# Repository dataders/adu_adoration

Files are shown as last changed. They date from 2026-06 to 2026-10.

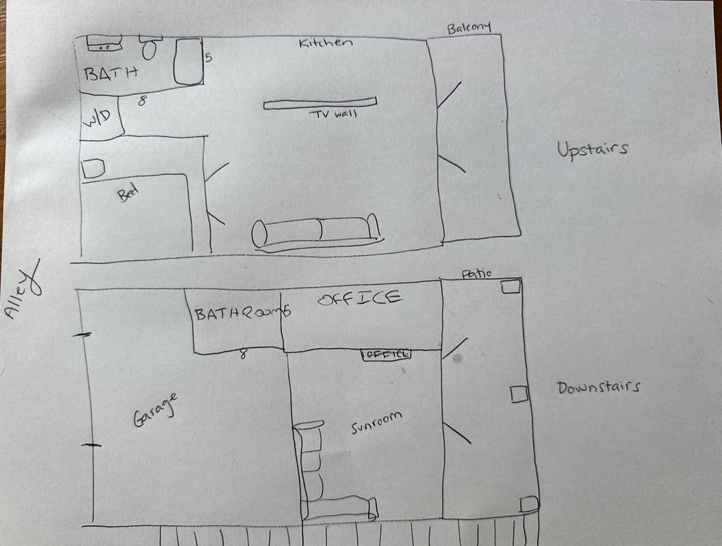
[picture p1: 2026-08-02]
images/12-handdrawn-two-level-design-basis.jpg

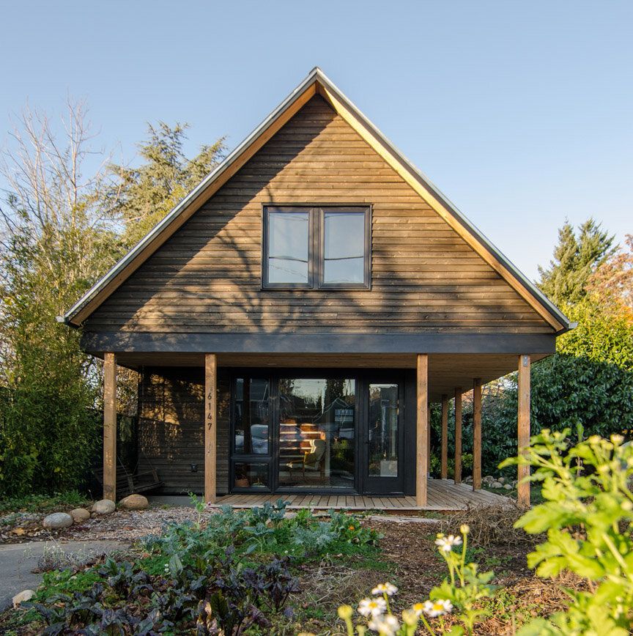
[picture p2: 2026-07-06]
inspiration/pin-407012885098092626-polyphon-architecture-design-llc-a-portland-oreg.jpg

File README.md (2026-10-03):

# ADU planning — 112 W 29th St, Richmond, Virginia

Design studies, source records, generated plans, and coordinated 3D artifacts for a
proposed detached accessory dwelling unit (ADU) at **112 W 29th St** (PID 43615 / PIN
S0001130005), Richmond, VA 23225.

## Project status

**Option F revision 2 is the current schematic owner study.** It is a 20 × 24 ft, two-story detached
building with a full-depth garage/shop and owner office below, an approximately 480 sf
one-bedroom apartment above, a south exterior stair, and stacked east patios. The working ridge datum is 19 ft 10 in; official height measurement and applicable zoning limits remain unverified.

Start with these files:

1. [Construction and engineering basis](output/pdf/adu-option-f-construction-engineering-basis.pdf)
   — schematic owner-coordination set, regenerated from the revision 2 geometry.
2. [Option F floor plans](apartment/option-f-recommended-development.svg) — current room,
   opening, stair, landing, and patio layout.
3. [Option F site plan](plan/site-plan-option-f-architect.pdf) — current placement,
   setbacks, access, and replacement-shed response.
4. [Interactive site model](model/site-model-3d.html#yard) — browser-based whole-site
   model with furnished floor cutaways and roof controls; serve over local HTTP as below.
5. [Coordination manifest](option-f-artifact-manifest.json) — machine-readable authority,
   version, invariants, and current-versus-historical artifact boundary.

Option E is the owner-sketch baseline. Options A–E and their model artifacts remain useful
design history, but they do not override Option F. Current model renderings use the same exported scene as the browser viewer. Earlier AI images are mood references only and do not govern geometry.

The earlier balcony-entry study in `plan/floor-plans-balcony-scheme.{svg,png}` and
`renderings/massing-3d-interactive.html` is retained as historical reference only. It does
not override the current Option F authority.

> This repository contains schematic design work, not sealed permit or construction
> documents. Survey, zoning determinations, code analysis, structural engineering, energy
> compliance, utility verification, and trade design still require qualified professionals.

## Working design basis

| Item | Current basis |
|---|---|
| Lot | 45 × 148 ft; approximately 6,660 sf; R-5 |
| Existing house | 1,303 sf; one story; built 1931 |
| Orientation | Alley west/rear; W 29th St east/front |
| ADU envelope | 24 ft east–west × 20 ft north–south; 480 sf gross per level |
| ADU vertical datums | Upper subfloor 9.25 ft; eave 16 ft; ridge 19.833 ft |
| ADU site position | 5 ft from alley/rear line and 5 ft from north line |
| Exterior access | 14 risers / 13 treads; connected south landing and 4-ft east patios |
| Replacement shed | 18 × 6 ft maximum envelope; 108 sf; 5 ft clear south of ADU access |
| Field measurement | 25 ft front setback confirmed 2026-06-28 |

Revision 2 retains a 23-ft-clear garage/shop bay and approximately 70-sq-ft northeast garden office. The lower hall is 39 inches clear. A northwest powder room stacks below the upper bath; upstairs laundry opens directly to common space. An L-shaped kitchen with peninsula replaces the island, and the TV moves to the bedroom partition. Schematic furniture clearances are 53.6 inches west of the peninsula, 38.4 inches from sofa to slider route, and 39.6 inches from dining chairs to counter. These are drawing checks, not code-compliance findings.

A separate [garden-room alternative](apartment/option-f-alternative-garden.svg) trades parking depth (18 ft clear) for approximately 121 sq ft of connected garden space. It is exploratory and does not override the current CAD or model.

[`model/option_f_geometry.py`](model/option_f_geometry.py) is the canonical geometry source. Generated drawings, CAD, browser mesh, and renderings must agree with it; stale generated artifacts do not override source intent. Finished headroom, wall/floor/roof assemblies, and appliance operation remain design holds.

The existing field-measured 12 × 18 ft shed is designated for removal. The assessor record
instead describes a 360 sf detached garage; reconcile that discrepancy during survey and
permitting.

## Quick start

Requires [uv](https://docs.astral.sh/uv/) and Python 3.11 or newer.

```sh
uv sync --group dev --group architecture
./bin/check
```

`./bin/check` runs Ruff lint and format checks, ty type checking, then the architecture
artifact suite. The architecture checks audit the Option F DXF and access geometry, compare
the coordination and model manifests, load the STEP solids with OpenCascade, verify actual door apertures and furniture clearances, compare the viewer against the canonical scene, validate render provenance hashes, inspect the GLB container, and parse committed PDF/PNG outputs. The model manifest counts physical solids separately from the ten nonphysical room zones. CI also runs the official Khronos glTF
Validator and requires zero errors and warnings.

Install optional commit hooks with:

```sh
uv run --group dev pre-commit install
```

## Regenerating artifacts

Run generators from the repository root. Commit source and regenerated artifacts together,
then run `./bin/check`.

```sh
# Floor-plan studies (SVG and PNG)
uv run python apartment/generate_floorplans.py

# Current Option F site plan (DXF and PDF)
uv run python plan/generate_site_plan.py --option F

# Current Option F building model (STEP, BREP, GLB, OBJ, manifest)
uv run --group architecture python model/generate_option_f_model.py

# Whole-site viewer and OBJ
uv run python model/generate_3d_model.py

# Schematic drawing set PDF
uv run python plan/generate_construction_basis_set.py

# Model-derived exterior and furnished cutaway images (Blender executable required)
blender --background --python model/render_model.py -- --views yard alley upper lower

# Preview static website and viewer (ES modules require HTTP, not file://)
uv run --no-project python -m http.server 8000
```

Open [the local website](http://localhost:8000/) or [the full-screen model](http://localhost:8000/model/site-model-3d.html#yard). Three.js 0.186.1 is vendored locally. Render provenance is recorded in [`renderings/model-render-manifest.json`](renderings/model-render-manifest.json), including hashes of the source scene, renderer, and each image.

Some historical Option E exports require FreeCAD or Sweet Home 3D. See
[model/README.md](model/README.md) before changing them.

## Repository map

| Path | Purpose |
|---|---|
| [`apartment/`](apartment/) | Historical studies A–E, revision 2 floor sheets, garden alternative, and generator |
| [`plan/`](plan/) | Current Option F and historical Option E site plans plus plan-set generator |
| [`model/`](model/) | Option F geometry contract, generators, CAD/mesh exports, whole-site viewer, and historical Option E models |
| [`output/pdf/`](output/pdf/) | Current combined concept and construction/engineering basis sets |
| [`renderings/`](renderings/) | Model-derived revision 2 images and archived AI mood references |
| [`images/`](images/) | Measured sketches, site photos, assessor sketch, and satellite references |
| [`documents/`](documents/) | Source property and owner PDFs |
| [`inspiration/`](inspiration/) | Curated and Pinterest-synced style references |
| [`sync/`](sync/) | Pull-only public Pinterest RSS sync |
| [`scripts/`](scripts/) | Repository validation implementation |
| [`bin/`](bin/) | Stable developer entry points |
| [`index.html`](index.html) | Static public project brief |
| [`requirements.html`](requirements.html) | Static high-level requirements brief |

Folder-specific documentation:

- [Floor-plan decisions and constraints](apartment/README.md)
- [3D formats and historical model boundary](model/README.md)
- [Source documents](documents/README.md)
- [Reference imagery](images/README.md)
- [Inspiration library](inspiration/README.md)
- [Pinterest sync](sync/README.md)
- [Agent/developer workflow](CLAUDE.md)

## Pinterest inspiration sync

The sync mirrors new images from a public Pinterest board into `inspiration/` through the
board RSS feed. It uses no login or API token and never pushes or deletes pins.

```sh
uv run --no-project python sync/pinterest_pull.py --dry-run
uv run --no-project python sync/pinterest_pull.py
```

See [sync/README.md](sync/README.md) for board setup and limitations.

## Open coordination items

- Confirm the working 5-ft north setback, roof projections, openings, and fire-separation
  strategy with Richmond zoning/building review.
- Reconcile field-measured shed dimensions with the assessor record.
- Verify survey, soil, grading, drainage, and utility locations.
- Resolve final roof/floor section, stair and guard details, structure, MEP, egress, and
  conditioned-area treatment with the design team.

## Research sources

Property data came from the saved [actDataScout report](documents/richmond-datascout-report-S0001130005.pdf)
and assessor sketch. Field sketches and measurements are in `documents/` and `images/`.

Zoning research was last checked August 12, 2026. The September design revision does not refresh legal or code findings. Earlier research used these City and Municode sources:

- [City of Richmond ADU guidance](https://www.rva.gov/planning-development-review/accessory-dwelling-units)
- [Richmond zoning ordinance, Chapter 30](https://library.municode.com/va/richmond/codes/code_of_ordinances)
- [R-5 district provisions](https://library.municode.com/va/richmond/codes/code_of_ordinances?nodeId=CH30ZO_ARTIVDIRE_DIV6SIMIREDI)
- [Accessory-building provisions](https://library.municode.com/va/richmond/codes/code_of_ordinances?nodeId=CH30ZO_ARTVISURE_DIV9ACBU)
- [Richmond Code Refresh](https://www.rva.gov/planning-development-review/code-refresh)

Relevant research notes cite §§30-410.4–.7, 30-620.1, 30-680.1, and 30-680.4. Recheck
current law and obtain written determinations before relying on those notes.

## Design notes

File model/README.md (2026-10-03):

# Option F revision 2 — shared 3D geometry

Current schematic owner study for a 24 × 20 ft ADU, with a garage and garden office below a 480-sq-ft gross apartment. Geometry is defined in [`option_f_geometry.py`](option_f_geometry.py). Site placement and existing buildings are working assumptions, not a surveyed or approved model.

## View the project

The viewer uses ES modules and must be served over HTTP. From repository root:

```sh
uv run --no-project python -m http.server 8000
```

Open [the project](http://localhost:8000/) or [the model](http://localhost:8000/model/site-model-3d.html#yard). Directly opening the HTML as `file://` is unsupported. Three.js 0.186.1 and its controls are vendored under `vendor/`; the viewer needs no CDN. The five view links are `#yard`, `#alley`, `#level1`, `#level2`, and `#site`. Drag to orbit, scroll/pinch to zoom, toggle the roof or furniture, and use furnished cutaways to inspect circulation. A static-image fallback is shown when WebGL cannot initialize.

## Current files and authority

- **`option_f_geometry.py`** — canonical feet/Z-up dimensions, openings, partitions, rooms, furniture, and checked circulation widths. Southwest building corner is origin; X east, Y north, Z up.
- **`generate_option_f_model.py`** — generates physical model components, cuts real wall apertures, and exports exact meshes plus neutral CAD.
- **`adu-option-f-scene.json`** — shared exact mesh data and semantic parts. Ten room zones are nonphysical metadata and are excluded from CAD/GLB/OBJ physical-solid counts.
- **`adu-option-f.step`**, **`.brep`** — physical schematic solids, in millimetres/Z-up. The manifest reports source geometry in feet.
- **`adu-option-f.obj`** — building mesh in feet/Z-up. **`adu-option-f.glb`** uses metres/Y-up.
- **`adu-option-f-manifest.json`** — version, physical-solid count, all semantic parts, datums, bounds, and circulation widths.
- **`site-model-3d.html`** — generated viewer with the exact canonical scene embedded. **`viewer-template.html`**, **`viewer.js`**, and **`viewer.css`** own its interface.
- **`site-model.obj`** — canonical building translated into site coordinates plus approximate context, in feet/Z-up. Pair with [`../plan/site-plan-option-f.dxf`](../plan/site-plan-option-f.dxf). `site-model.mtl` is retained from the earlier export and does not define current geometry.
- **`render_model.py`** — Blender renderer for model-derived exterior and furnished cutaway images; adds materials, lighting, ground, and sparse landscape context rather than inventing building geometry.

Regenerate in dependency order:

```sh
uv run --group architecture python model/generate_option_f_model.py
uv run python model/generate_3d_model.py
blender --background --python model/render_model.py -- --views yard alley upper lower
./bin/check
```

The four images are `renderings/option-f-yard-model.png`, `option-f-alley-model.png`, `option-f-upper-cutaway.png`, and `option-f-lower-cutaway.png`. `renderings/model-render-manifest.json` records source scene, image, and renderer SHA-256 hashes. Run all four views after geometry changes. Earlier AI images remain historical mood references.

## Revision 2 decisions

The 39-inch-clear downstairs hall connects the powder room and approximately 70-sq-ft garden office while retaining 23 ft of parking depth. Upstairs has an L-shaped kitchen and peninsula, common-space laundry access, and a TV on the bedroom partition. A separate approximately 121-sq-ft garden-room study shortens parking depth to 18 ft; it is not represented in the selected model.

Vertical datums remain +9.25 ft upper subfloor, +16 ft eave, and +19.833333 ft ridge. The exterior stair has fourteen risers from the +0.5 ft ground landing to the upper floor. The roof assembly allowance is provisional; finish headroom and actual assemblies require professional design. Four-foot exterior patios are principally circulation, and guard details and usable clear widths remain unresolved.

### Historical Option E FreeCAD model

Files below are retained only to document the previous Option E study. They are
not current geometry and must not be used to override Option F plans or models.

- **`adu-option-e.FCStd`** — editable two-level Option E model. Organized into
  Level 1, Level 2, exterior access, and roof groups, with named walls, room
  zones, openings, fixtures, cabinetry, patios, balcony, and 13-step exterior
  stair. Objects retain source/category/level metadata.
- **`adu-option-e.glb`** — compact, color-preserving glTF 2.0 binary for WebGL,
  `<model-viewer>`, Three.js, Blender, and other real-time viewers.
- **`adu-option-e.obj`** — generic triangulated Wavefront OBJ export.
- **`adu-option-e-arch.obj`** + **`adu-option-e-arch.mtl`** — FreeCAD BIM/Arch
  Wavefront export with named objects and color materials.
- **`adu-option-e-sweethome.obj`** + **`adu-option-e-sweethome.mtl`** — same
  Arch geometry transformed from millimetres/Z-up to centimetres/Y-up; preferred
  Sweet Home 3D import.
- **`adu-option-e-sweethome-simple.obj`** — single-mesh, no-material fallback
  for Sweet Home 3D installations where the multi-material loader stalls.
- **`adu-option-e.step`** — named, color-preserving STEP export for CAD tools.
- **`adu-option-e.brep`** — ASCII OpenCASCADE geometry for low-level textual
  inspection. Exact but noisy in Git diffs.
- **`adu-option-e-manifest.json`** — deterministic semantic summary of every
  object's name, category, level, color, bounds, area, volume, and topology;
  preferred human-readable Git diff.
- **`adu-option-e-level-1.png`**, **`adu-option-e-level-2.png`**, and
  **`adu-option-e-axon.png`** — checked FreeCAD views for quick review.
- **`generate_freecad_adu.py`** — deterministic native-FreeCAD generator using
  the dimensions in `apartment/generate_floorplans.py`.
- **`export_freecad_formats.py`** — regenerates all interchange and diff exports
  from the saved FCStd model.
- **`convert_arch_obj_to_glb.py`** — converts the color-material Arch OBJ from
  millimetres/Z-up to a web-oriented GLB in metres/Y-up.
- **`prepare_sweethome_obj.py`** — converts the Arch OBJ units and up-axis for
  an exact-scale Sweet Home 3D import.
- **`BuildSweetHomeProject.java`** — uses Sweet Home 3D's bundled model API to
  create separate, non-overlapping `adu-option-e-level-1.sh3d` and
  `adu-option-e-level-2.sh3d` editable floor plans. `adu-option-e-floorplans.sh3d`
  is retained as a clean Level 2 view. Each keeps the fallback OBJ as a hidden
  3D reference.
- **`export_colored_step_gui.py`** — FreeCAD GUI startup script that overwrites
  the headless STEP baseline with names and native AP214 presentation colors.
- **`apply_freecad_view.FCMacro`** — reapplies stored colors and the saved
  axonometric view after a headless regeneration.

FreeCAD 1.1.3 on macOS bundles Qt 6.8.3. Qt's ARM CPU probe fails inside the
Codex sandbox because that environment blocks `sysctlbyname`; run this command
outside the sandbox. FreeCAD's bundled Python plus explicit module path avoids
the macOS `freecadcmd` positional-script issue:

```sh
PYTHONPATH=/Applications/FreeCAD.app/Contents/Resources/lib \
  /Applications/FreeCAD.app/Contents/Resources/bin/python \
  model/generate_freecad_adu.py
```

Then open `adu-option-e.FCStd` in FreeCAD and run
`apply_freecad_view.FCMacro` from **Macro → Macros…**. FreeCAD stores geometry
in millimetres; source coordinates and plan metadata remain in feet.

Regenerate the headless interchange exports:

```sh
PYTHONPATH=/Applications/FreeCAD.app/Contents/Resources/lib \
  /Applications/FreeCAD.app/Contents/Resources/bin/python \
  model/export_freecad_formats.py

uv run --with trimesh --with numpy python3 \
  model/convert_arch_obj_to_glb.py

uv run --with trimesh --with numpy python3 model/prepare_sweethome_obj.py

/Applications/FreeCAD.app/Contents/Resources/bin/freecad \
  -u /tmp/adu-freecad-export-user.cfg \
  -s /tmp/adu-freecad-export-system.cfg \
  "$PWD/model/export_colored_step_gui.py"
```

This remains a design-development model, not construction documentation.
Architect must verify floor/roof section, structure, stair and guards, egress,
fire separation, plumbing, and zoning treatment.

## Heights used (estimates — field-verify)

| building | eave | ridge | notes |
|---|---|---|---|
| house | 10′ | 20′ | 1-story, gable ridge E–W, green siding |
| replacement shed | 7′ | 9.5′ | 18×6 low-profile massing, red slider on east gable end |
| ADU Option F | 16′ | 19′-10″ | +9′-3″ upper-subfloor basis; north eave and west rake flush pending zoning |

Footprints and setbacks follow the working site-plan basis (owner-measured front setback 25′, proposed ADU 5′ off alley / 5′ off north line), pending survey and zoning review.
Preliminary massing only — not for construction.

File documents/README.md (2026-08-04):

# Source documents

| File | What it is | Source |
|---|---|---|
| `richmond-datascout-report-S0001130005.pdf` | Full City of Richmond property report — lot dims, building sub-areas, photo, assessment, deed history | actDataScout, PIN `S0001130005` |
| `assessor-building-sketch-43615.pdf` | Assessor building footprint sketch with dimensions | actDataScout / PID 43615 |
| `site-plans-handdrawn-compressed.pdf` | Owner's hand-drawn site plans (3 pages, three scales) | Owner |

Notes:
- `site-plans-handdrawn-compressed.pdf` is downsampled from the original ~57 MB phone-photo PDF,
  which the owner retains outside the repository.
- actDataScout lookups: https://www.actdatascout.com/RealProperty/Virginia/Richmond

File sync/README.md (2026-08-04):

# Pinterest → `inspiration/` sync

One-way mirror of a **public** Pinterest board into this repo's
[`inspiration/`](../inspiration/) folder, using the board's RSS feed. No
Pinterest login, no API token, no signup.

## Quick start

```sh
# 1. Point it at your board (public boards only) — do this once:
echo 'https://www.pinterest.com/<user>/<board>/' > sync/board.txt

# 2. Preview what it would pull:
uv run --no-project python sync/pinterest_pull.py --dry-run

# 3. Actually pull new pins into inspiration/:
uv run --no-project python sync/pinterest_pull.py
```

You can also pass the URL directly instead of using `board.txt`:

```sh
uv run --no-project python sync/pinterest_pull.py https://www.pinterest.com/<user>/<board>/
```

Re-run it any time — it's idempotent. Already-downloaded pins are tracked in
[`manifest.json`](manifest.json), so a re-run only fetches **new** pins.

Synced pins land as `inspiration/pin-<id>-<slug>.jpg`. Your six hand-curated
`NN-*.jpg` references are never touched.

## What this does and doesn't do

| | |
|---|---|
| ✅ Pull new pins from a public board | Reads `<board-url>.rss` |
| ✅ Full-res images when available | Rewrites the CDN URL to `/originals/`, falls back to the RSS thumbnail |
| ✅ Idempotent re-runs | `manifest.json` records every pulled pin |
| ✅ Leaves your curated files alone | Only writes `pin-*.jpg` |
| ❌ **Push** repo images up to Pinterest | Needs the API v5 + OAuth token (see below) |
| ❌ **Delete-sync** | A pin removed on Pinterest is flagged (not deleted) locally |
| ❌ Private/secret boards | RSS is only exposed for public boards |

This is **pull-only** because that's the part that needs no credentials — which
is what you asked for. Creating or editing pins on Pinterest is impossible
without the authenticated API.

## Why not a Pinterest MCP?

There is no Pinterest connector in the Claude MCP directory (checked the
registry — it has monday.com, Miro, etc., but nothing Pinterest). So there's
nothing to "flip on"; a real integration has to talk to Pinterest's own API or,
as here, its RSS feed.

## Upgrading to full bidirectional (later, if you want it)

True two-way sync (pushing local images up as new pins) requires the
[Pinterest API v5](https://developers.pinterest.com/docs/api/v5/):

1. Create a Pinterest **business account** and a developer **app** at
   <https://developers.pinterest.com/>.
2. Request **trial access** (self-serve) — enough for a personal board.
3. Generate an **OAuth access token** with the `boards:read`, `pins:read`, and
   `pins:write` scopes.
4. Swap the RSS reader here for API calls:
   - Pull: `GET /v5/boards/{board_id}/pins` (full metadata + original images).
   - Push: `POST /v5/pins` with `media_source` of type `image_base64` to upload
     a local file as a new pin.

The `manifest.json` format here already tracks the pin↔file mapping you'd need
to avoid duplicate uploads, so it carries over.

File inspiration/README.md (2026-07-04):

# Inspiration

Reference photos of garage-ADUs / homes whose style we like, to steer the ADU design.

| File | Style notes |
|---|---|
| `01-gold-siding-black-windows-bay-tower.jpg` | Warm ochre lap siding, black windows, decorative shingled gable + 2-story angled bay/tower. Modern-traditional. |
| `02-modern-taupe-shed-roof-awning-windows.jpg` | Taupe lap siding, low **shed/skillion roof**, tilted awning-style windows, single garage bay, exterior side stair. Contemporary. |
| `03-craftsman-gray-red-trim-carriage-door.jpg` | Gray-green lap siding, white + **red window trim & red door**, wood **carriage garage door**, exposed rafters / knee braces, gable roof, lantern sconces. **Closest match to our 1931 Craftsman bungalow.** |
| `04-olive-carriage-door-balcony-cottage.jpg` | Small olive/tan garage, green carriage door, side deck/balcony, hip roof. Coastal-cottage. |
| `05-brick-shed-roof-black-windows-wood-door.jpg` | Red **brick**, shed/skillion roof, black windows, warm wood louvered garage door + transom. Urban/Richmond-appropriate context. |
| `06-modern-olive-bronze-windows-corner-glass.jpg` | Olive lap + panel siding, bronze/black windows, shed roof, big **corner-glass** windows, sliding patio door. Contemporary indoor-outdoor. |

**Themes emerging:** two-story garage-below / living-above; **lap siding** on most; **dark/black windows**
recur; **carriage-style or wood garage doors**. Two directions are taking shape —
(A) **Craftsman-traditional** (01, 03, 04) that matches the existing bungalow, vs.
(B) **modern shed-roof with dark windows** (02, 05, 06); 05 adds a **brick** option that suits Richmond.

**Existing-house style to complement:** 1931 Craftsman bungalow — sage-green lap siding, gabled porch
with tapered columns, wide eaves / exposed rafter tails, divided-light sashes (photo on page 2 of
`documents/richmond-datascout-report-S0001130005.pdf`).

Add new references as `NN-short-description.jpg`.

Files named `pin-<id>-<slug>.jpg` are auto-pulled from a Pinterest board by
[`sync/pinterest_pull.py`](../sync/) and tracked in `sync/manifest.json` — leave the
naming as-is so re-runs stay idempotent.

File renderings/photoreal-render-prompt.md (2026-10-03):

# Option F revision 2 — rendering brief and image prompts

Updated September 30, 2026. Design version: `2026-09-30-option-f-basis-v2`.

## What has actually been generated

The current images are deterministic Blender Cycles architectural studies from
[`adu-option-f-scene.json`](../model/adu-option-f-scene.json), not AI-generated
photographs. Their source, renderer, and image hashes are recorded in
[`model-render-manifest.json`](model-render-manifest.json).

| View | Current generated image |
|---|---|
| Yard / southeast exterior | [Yard model render](option-f-yard-model.png) |
| Alley / southwest exterior | [Alley model render](option-f-alley-model.png) |
| Upper apartment cutaway | [Upper cutaway](option-f-upper-cutaway.png) |
| Lower garage and garden office cutaway | [Lower cutaway](option-f-lower-cutaway.png) |

All four are 1800 × 1200 pixels, rendered at 64 samples. Materials and context
are illustrative; the double-teardrop siding appearance is an approximate bump
profile, not a selected product. The older `*-photoreal*.png` and AI interior
images remain historical mood references. They have not been regenerated for
revision 2. The [previous prompt brief](archive/photoreal-render-prompt-v1.md)
is archived for provenance.

The prompts below are the updated brief for future image refinement. They did
not generate the four current Blender images. Keep any future AI refinements
separately named and labeled until their geometry has been checked.

## Source hierarchy and reference bundle

1. [Shared geometry contract](../model/option_f_geometry.py): dimensions,
   datums, rooms, openings, partitions, and furniture positions.
2. [Exported scene](../model/adu-option-f-scene.json),
   [STEP](../model/adu-option-f.step), and [GLB](../model/adu-option-f.glb):
   coordinated geometry. Source/OBJ coordinates are feet, Z-up; GLB is metres,
   Y-up; STEP is millimetres.
3. [Lower plan](../apartment/option-f-level-1.png),
   [upper plan](../apartment/option-f-level-2.png), and
   [site plan](../plan/site-plan-option-f.png): visual layout and placement checks.
4. The matching current model image above: fixed camera and geometry reference
   for any image-to-image refinement.
5. Actual [yard photo](../images/10-backyard-garden-facing-north.jpg),
   [alley photo](../images/11-backyard-alley-parking-facing-east.jpg), and
   [Craftsman reference](../inspiration/03-craftsman-gray-red-trim-carriage-door.jpg):
   context and material character only.

Resolve disagreements in the source geometry and regenerate affected outputs.
Never recover dimensions from an earlier AI image. The
[larger garden-room alternative](../apartment/option-f-alternative-garden.svg)
is a separate, unselected study and must not be mixed into these renders.

## Shared master prompt

Append one camera block below. Supply its matching model image and plan as
references; a text prompt alone does not establish dimensional fidelity.

```text
Create an architectural visualization of Option F revision 2. Preserve the
supplied model's silhouette, proportions, openings, partitions, furniture
locations, stair, landing, and balconies. Refine light and materials only.
If a reference is missing or ambiguous, flag it instead of inventing geometry.

GEOMETRY
Exactly two stories; enclosed footprint 24 ft east-west × 20 ft north-south.
West is the alley; east is the yard. The gable ridge runs east-west. No dormers.
Project datums: ground slab top +0.5 ft, upper floor +9.25 ft, eave +16 ft,
ridge +19.833333 ft. The floor-to-floor rise is 8.75 ft, not 9.25 ft.
Roof slope follows these datums, approximately 4.6:12. North eave and west
rake stay flush. These are project datums, not a verified legal grade height.

ACCESS AND OPENINGS
The straight south stair rises west-to-east, with 14 risers of 7.5 inches,
13 treads, an 11-ft run and 4-ft width. Treads stop at the upper landing.
The flat 4-ft-deep south landing continues east and turns openly onto the
4-ft-deep east balcony. Keep the connection free of a crossing guard.
The east patios are approximately 19.5 ft long and stack vertically.
One hinged upper entry and one 5-ft living window are on the south wall.
The west garage door is below the single upper bedroom window.
East: a lower shop window and 6-ft garden-office slider near the north end;
above, a 6-ft living slider near the south end and dining window farther north.
Use exact opening positions from the model. No north-wall openings.

ROOMS AND CIRCULATION
Below: 23-ft-clear garage/shop, 39-inch-clear hall, powder room, mechanical
support, and approximately 70-sq-ft northeast garden office. No shower,
bedroom, laundry, or additional exterior office door downstairs.
Above: west bedroom and closet, northwest full bath, laundry cupboard with
access directly from common space, and open east living/kitchen/dining.
Use the L-shaped kitchen and attached peninsula, not a freestanding island.
The sofa faces the TV on the bedroom partition; no freestanding media wall.
Preserve the 53.6-inch kitchen approach, 38.4-inch sofa-to-slider route and
39.6-inch dining-chair-to-counter gap shown by the schematic furniture test.
Do not enlarge rooms, move walls, or substitute the 121-sq-ft garden alternative.

APPEARANCE
Restrained Craftsman character: sage/gray-green double-teardrop-style siding,
cream trim and guards, muted red accents, charcoal roof, warm wood decking.
Keep structural silhouettes and window divisions from the supplied model.
No invented braces, roof overhangs, gable vents, canopies, or extra openings.
Color and finish are illustrative selections. Use soft directional daylight,
readable shadows, natural material texture and a calm, uncluttered background.
No people, labels, dimensions, logos or watermarks. Do not imply permit approval.
```

## Yard exterior camera

Reference: current yard model image, both plans, site plan, and actual yard photo.

```text
View from southeast toward northwest. East gable and stacked balconies are
primary; south stair remains visible on camera-left. Frame the complete stair,
flat landing, southeast turn, both east sliders and both balcony levels.
Keep the upper slider south and the lower garden-office slider north.
Use the supplied model camera for a directly comparable architectural study.
For an explicitly requested photographic variant, use a natural 28–35 mm lens
and maintain all model geometry; do not use perspective to conceal mismatches.
```

## Alley exterior camera

Reference: current alley model image, both plans, site plan, and actual alley photo.

```text
View from southwest toward northeast. West gable, garage door and one upper
bedroom window are primary. South stair is camera-right, rising away from the
alley before reaching a flat landing. Show the connected landing and east turn.
Do not place the garage door on the east facade or continue treads along the
landing. Any site context must follow the site plan: ADU 5 ft from west and
north lot lines; replacement shed 18 × 6 ft, with a 5-ft gap south of access.
Shed and existing-house heights are approximate; their masses are optional
context, not required parts of a close building view.
```

## Upper apartment cutaway

Reference: current upper cutaway and upper floor plan.

```text
Elevated southeast three-quarter cutaway looking northwest. Remove roof and
clip architectural walls 3 ft above the +9.25-ft upper floor; cap cut surfaces.
Keep furniture at its modeled height, and show the whole apartment and balcony.
Read the west bedroom/closet, northwest bath, direct-access laundry, attached
kitchen peninsula, northeast dining, southeast sofa and west-facing TV clearly.
Keep door apertures visible. Do not substitute an imagined eye-level room,
widen circulation, relocate appliances or add a freestanding kitchen island.
```

## Lower garage and garden-office cutaway

Reference: current lower cutaway and lower floor plan.

```text
Elevated southeast three-quarter cutaway looking northwest. Remove the upper
story and roof, clip architectural walls 3 ft above the +0.5-ft slab, and cap
cut surfaces. Show an empty garage/shop so its clear depth can be read.
Retain the hall, powder room, mechanical support, furnished garden office and
northeast yard slider. Preserve actual door openings and the 39-inch hall.
Do not fill the garage with a giant vehicle proxy or enlarge the office.
```

## Reproduce the current model images

From the repository root, with Blender available:

```sh
uv run --group architecture python model/generate_option_f_model.py
blender --background --python model/render_model.py -- --views yard alley upper lower --width 1800 --samples 64
uv run python model/generate_3d_model.py
uv run python plan/generate_construction_basis_set.py
./bin/check
```

After geometry changes, regenerate plans too. Inspect all images against the
current plans, including openings, stair transitions, furniture and circulation.
Refresh PDF covers and the provenance manifest together. Finished headroom,
assemblies, structure, guards, survey and permits remain professional design items.

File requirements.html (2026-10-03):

Skip to content

Option F · revision 2

# Project Requirements

112 W 29th St · Detached garage apartment

Status

Schematic

Apartment

480 sf gross

Lot

R-5 · 6,660 sf

High-level requirements

## The project brief, grouped by decision area.

Revision 2: a two-story detached accessory dwelling over a garage, with simpler kitchen circulation, a wider lower hall, common-space laundry access, and an explicit larger-garden-room alternative. This page is a planning brief, not a code determination or construction document.

Footprint20 x 24 ft enclosed

Height basis19 ft 10 in ridge

Setbacks5 ft north + rear

AccessSouth stair + east patios

Aesthetics

## House-compatible, modern carriage-house character.

- Use double-teardrop siding to match the existing house's siding profile; final color remains a separate owner selection.
- Keep Craftsman influence visible through proportions, siding, trim depth, divided-light windows, and a carriage-style garage door.
- Keep the building modern and restrained: simple massing, clear roof shape, durable details, and no decorative overcomplication.
- Make the yard-facing east side feel open and residential, with stacked patios and large sliders.
- Treat the alley-facing west side as serviceable but composed, with garage access below and one bedroom window above.

Floor plan

## A clear plan, with an explicit garage tradeoff.

- Current Level 1 basis: a 23-ft-clear garage/shop bay, garage-support/mechanical area, 39-inch-clear hall, powder room, and approximately 70-sq-ft owner garden office. Garage separation remains a professional design item.
- Level 2 contains the one-bedroom apartment: bedroom, northwest full bath, laundry cupboard accessed directly from the common space, and open living/kitchen/dining.
- Provide two bathrooms total: one lower powder room and one upper full bath in a stacked wet core.
- Use exterior south stair access so the upstairs apartment keeps its full 480 sf gross footprint.
- Connect the stair to a continuous upper landing and 4-ft-deep east patio/balcony. Treat the balcony primarily as access; verify clear width after guards and test any seating separately.
- Use the revised L-shaped kitchen and peninsula; remove the freestanding island and media wall. Kitchen approach is 53.6 inches, the sofa-to-slider route is 38.4 inches, and the dining-chair-to-counter gap is 39.6 inches in the schematic furniture test. Verify appliance door swings and finished dimensions.
- Compare the separate garden-room alternative: 18-ft-clear parking with approximately 121 sq ft of connected garden space. This alternative is exploratory and is not the selected CAD/model basis.

Site planning

## Test the working setbacks against the surveyed lot.

- Use the current 45 x 148 ft lot basis, approximately 6,660 sf, with alley/rear access on the west and W 29th St frontage on the east.
- Place the ADU 5 ft from the alley/rear line and 5 ft from the north property line in the current concept.
- Maintain the field-measured 25 ft front setback basis for the existing house until survey confirms it.
- Remove the field-measured 12 x 18 ft shed and replace it with a low-profile 18 x 6 ft maximum shed envelope.
- Keep 5 ft clear between the replacement shed and the south stair/access band.
- Reconcile the field-measured shed with the assessor record that describes a 360 sf detached garage.

Zoning

## Re-verify the researched R-5 planning basis.

- The August 12, 2026 research brief recorded one ADU in residential districts on the same lot as a single-family dwelling. Re-verify current guidance before relying on this allowance.
- The August 12, 2026 research brief recorded an ADU area limit of the greater of one-third of the main dwelling floor area or 500 sf. Re-verify that limit and area treatment; the upper apartment is 480 sf gross.
- R-5 yard basis to verify: 25 ft front, 5 ft side, and 5 ft rear.
- R-5 lot coverage cap to track: 35 percent. Current planning math is approximately 1,891 sf enclosed coverage, or about 28.4 percent of the lot, before official survey/coverage treatment.
- Confirm whether the lower owner office/garden room and powder room count toward ADU floor area.
- Confirm roof projections, gutters, wall openings, fire-separation assumptions, and any nonconforming lot-width treatment with Richmond Zoning in writing.

Height + section

## Stay under the accessory-building height cap.

- Current vertical basis: upper subfloor at 9.25 ft, eave at 16 ft, ridge at 19.833 ft.
- Keep the planned ridge below the researched 20 ft residential accessory-building height cap.
- Confirm official height measurement from final average grade and finished roof assembly.
- Prove finished sloped-ceiling headroom at fixtures, furniture, stairs, and circulation. A provisional 0.85-ft roof assembly allowance leaves approximately 5.9 ft at the wall and 9.73 ft at the ridge; this is not a compliance finding.
- Keep north eave and west rake flush at setback-side roof edges unless written zoning review allows projections or the building moves inward.

Building code

## Resolve safety before construction drawings.

- The earlier research used the 2021 Virginia Residential Code and Richmond residential review process. Confirm the applicable code edition and local requirements for the actual permit application.
- Detail garage-to-dwelling separation: rated ceiling/supports, protected door, sealed penetrations, alarms, and no shared garage return air.
- Select bedroom egress window product that meets final clear-opening and sill requirements.
- Verify stair rise/run, headroom, landings, handrails, guard height, guard openings, and exterior-stair framing.
- Coordinate safety glazing, water management, air sealing, firestopping, insulation, and ventilation around large sliders and openings.

Utilities + systems

## Keep systems compact and serviceable.

- All-electric basis: heat pump HVAC, heat-pump water heater, induction range, and electric dryer.
- Stack plumbing in the wet core and route penetrations away from engineered member no-cut zones.
- Verify sanitary route and invert, water service/meter requirements, electrical service capacity, feeder routing, and exterior equipment clearances.
- Confirm drainage, stormwater path, grading, tree/root impacts, erosion controls, and construction access before final siting.
- Coordinate bath exhaust, range exhaust, dryer venting, whole-dwelling ventilation, condensate drains, and exterior noise constraints.

Code Refresh

## Track possible rule changes, but do not rely on them yet.

- Zoning research on this page was last checked August 12, 2026. The website redesign does not constitute a new legal or code review.
- The prior brief expected Code Refresh Draft 3 on August 17, 2026. That date has passed; check the latest published drafts and adopted ordinance before design commitments.
- Watch ADU size, unit count, lot coverage, height, district mapping, preservation incentives, and accessory-dwelling height limits.
- Keep the current 480 sf apartment layout unless an adopted code change and professional review justify revisiting the program.

Professional review

## Open holds before permit or construction.

- Obtain boundary/topographic survey, utility locates, soil/foundation basis, and written zoning confirmation.
- Have licensed architect and engineer complete permit drawings, structural calculations, exterior-stair/deck design, assemblies, energy compliance, and trade coordination.
- Submit required architectural, structural, electrical, plumbing, mechanical, and any demolition or zoning compliance permits.
- Use approved permit drawings and field-verified dimensions as the construction authority.

Source trail

Construction and engineering basis Current floor plans Current site plan Richmond ADU guidance (https://www.rva.gov/planning-development-review/accessory-dwelling-units) Richmond Code Refresh (https://www.rva.gov/planning-development-review/code-refresh)

Design revised September 2026 · Code research last checked August 12, 2026

Back to plan brief

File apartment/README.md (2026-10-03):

# Apartment layout — the 1-bed above the garage

How to plan (and keep iterating) the ~480 sf apartment on level 2 of the
20 × 24 ADU. Six worked schemes live here as full sheets (garage level +
apartment level, furnished, annotated):

| sheet | stair | bedroom | living | headline trade |
|---|---|---|---|---|
| **[`option-f-recommended-development`](option-f-recommended-development.png)** | **exterior**, south face from alley | west (alley) | center + east | **REVISION 2:** clear circulation, northwest wet core, peninsula kitchen, explicit garden-room trade |
| [`option-e-primary-design-basis`](option-e-primary-design-basis.png) | **exterior**, south face from alley | west (alley) | center + east | **OWNER-SKETCH BASELINE:** corrected roof-aware kitchen, programmed lower level |
| [`option-a-living-east`](option-a-living-east.png) | interior, north wall | west (alley) | east + south | living gets the yard view; bedroom sits over the garage door |
| [`option-b-bedroom-east`](option-b-bedroom-east.png) | interior, north wall | east (yard) | center + south | quiet bright bedroom; living loses the yard view |
| [`option-c-exterior-stair`](option-c-exterior-stair.png) | **exterior**, east face | west (alley) | east + south | ~46 sf more apartment *and* garage; you arrive outside |
| [`option-d-south-stair-roof-aware`](option-d-south-stair-roof-aware.png) | **exterior**, south face from alley | west (alley) | center + east | direct alley stair; kitchen moves to full-height gable zone; smaller shed required |

Regenerate after editing: `uv run python3 apartment/generate_floorplans.py`
(pure-stdlib Python → SVG; PNGs render via the local headless chromium,
or `rsvg-convert` if present).

## Current design - Option F revision 2

Revision 2 is an owner design study with coordinated drawings and model geometry.
The alternatives are choices for review; the current layout has not been approved
for construction or demonstrated to satisfy finished headroom requirements.

- [Level 1](option-f-level-1.svg): 23 ft clear garage depth, 39 in clear protected
  hall, northwest powder room, mechanical/storage room, 70 sf northeast owner room.
- [Level 2](option-f-level-2.svg): northwest bath with pocket door, direct laundry
  access, L kitchen with peninsula, west-facing sofa and partition-mounted TV.
- Measured routes: 53.6 in west of peninsula, 38.4 in beside sofa to east slider,
  39.6 in between dining chairs and kitchen. These are planning clearances;
  appliance-door envelopes and actual furniture still require verification.
- [Garden-room alternative](option-f-alternative-garden.svg): approximately 121 sf combined
  owner/garden room, trading garage depth from 23 ft to 18 ft. This is an exploratory
  floor plan only; no corresponding CAD model or structural solution is claimed.
- Exterior walls, openings, south stair and connected 4 ft patios retain the same basis.

The shared contract is [`model/option_f_geometry.py`](../model/option_f_geometry.py).
Partitions, exterior openings and furniture feed the floor-plan generator; its
per-floor output also appears in the PDF. Geometry version is
`2026-09-30-option-f-basis-v2`. Project Z: lower slab +0.5 ft, upper subfloor
+9.25 ft, eave +16 ft, ridge +19.833 ft. Roof slope follows those heights
(approximately 4.6:12). A provisional 0.85 ft roof allowance illustrates headroom;
it is not a selected assembly or a compliance determination.

Generate current assets without changing historical A-E outputs:

```sh
uv run python apartment/generate_floorplans.py --option-f
uv run python plan/generate_site_plan.py --option F
uv run python plan/generate_construction_basis_set.py
```

The previous F sheet is retained in [archive/option-f-v1.svg](archive/option-f-v1.svg).
The [concept PDF](../output/pdf/adu-option-f-concept-plan-set.pdf) includes the site,
each revised floor, and the garden alternative. The 11-sheet
[basis PDF](../output/pdf/adu-option-f-construction-engineering-basis.pdf) retains
engineering/code assumptions for professional reconfirmation.

## The fixed constraints (get these in your head first)

The following are inherited working assumptions. Final zoning, code and survey
confirmation remains outside this design revision:

1. **Envelope: 24' E-W × 20' N-S.** With 2×6 exterior walls the interior is
   ~23' × 19' = **437 sf net** (480 sf gross — under the 500 sf R-5 cap, so
   there is no bonus square footage to find; only better arrangements).
2. **The north wall is 5' off the property line.** This meets the working R-5
   setback. Keep the north wall **blank** at concept stage for privacy and a
   simple fire-separation strategy until the architect confirms projections and openings.
   This is a gift, not a problem:
   every apartment needs one blank wall for the stair, bath, kitchen run,
   and closets. Put all of them there and you lose nothing.
3. **Light and view: south + east.** South face looks over the selected low-profile 18 × 6 shed and
   gets all-day sun; east faces your yard and the back of the main house
   (morning sun, and the "who's home" sightline). West = alley, fine for
   secondary windows. So **living spaces want the SE corner**.
4. **The garage door is on the west (alley) face, below.** Whatever room is
   above it hears it. A bedroom there wants a quiet side-mount opener.
5. **≤ 20 ft total height** (R-5 accessory cap) means the upper floor will
   likely have a low-ish plate or some sloped ceiling. Put low-headroom
   zones over things that don't need standing height at the edges: the bed,
   the tub, closets — not the kitchen counter.

   **Roof warning:** A–C are plan studies, not section-verified layouts. Current
   massing uses an E–W ridge with 16' eaves and a 19'-10" ridge, so ceiling height
   falls toward the north and south walls. At the working 9'-3" upper-subfloor
   datum, the roof exterior is only about 6'-9" above the upper floor at
   the eaves before subtracting roof structure and finishes, so a full-height
   refrigerator cannot sit against those walls. Option D responds by moving the tall
   kitchen to the east gable-end wall near the ridge and pulling standing bath
   fixtures into the central high-headroom band. Options E and F adopt the same roof
   logic while preserving the owner's preferred two-level organization. Final floor/roof section still
   controls; changing roof overhang alone does not create interior headroom.

## Owner-sketch baseline — Option E

Option E starts from the [owner's preferred two-level sketch](../images/12-handdrawn-two-level-design-basis.jpg),
not from Option D. It preserves the sketch's core ideas:

- garage left, bathroom north-center, office northeast, sunroom directly below it,
  and an exterior east patio on level 1;
- west bedroom, west bath/laundry, open living room, central TV wall, and balcony on level 2;
- exterior stair beginning at the west alley, rising east along the south wall,
  then wrapping around the southeast corner in a 3'-6"-wide open connection to
  an upper east patio stacked directly above the level-1 patio;
- a 16' × 4' covered level-1 south patio below the raised landing after the stair
  flight, connecting around the southeast corner to the east patio;
- sliding-glass apartment entrance from that upper east patio.

One deliberate correction: kitchen is no longer a tall cabinet run under the sloping north eave.
Refrigerator and pantry move to the full-height east gable wall; sink and range move to an island
beneath the E–W ridge. This is a design basis, not a construction plan. Architect must verify roof
section/headroom, structure, egress, stair geometry, plumbing, fire separation, and whether enclosed
level-1 office/sunroom area changes zoning treatment or the 500 sf ADU living-area calculation.
The sketch's room proportions also leave only about 13'-6" of clear garage depth inside the current
20 × 24 footprint; architect must rebalance garage/sunroom widths or enlarge/reorient the footprint
to fit a typical 16' vehicle.

## The three decisions that ARE the layout

Iterating a plan this small is really just re-answering three questions.

**Decision 1 — stair inside or outside?** This is the big one: a straight
interior stair costs ~46 sf on *each* floor (a 3'×13' slot plus landing).
Inside (A/B): one weather-tight entry, feels like a house, easier
aging-in-place; costs you a chunk of the garage and the apartment.
Outside (C/D/E/F): the apartment keeps all 437 sf; C leaves the garage open,
while D/E/F place the stair on the south face and E/F program the lower level.
Exterior access means you carry groceries up in the rain, and the stair adds
bulk to the yard facade. If inside, the stair goes on the north wall,
full stop — it's the only room-sized thing that never needs a window.

**Decision 2 — where's the wet core?** Bath + laundry + kitchen want to
share plumbing drops, and the drops land in the garage (easy to box out —
another reason this is cheap to get right). A–C stack one **NW bath
(6'-4" × 5'-8" with shower + stacked W/D)** over a garage mech/workbench
corner. D/E explored fixture placement toward the ridge. Revised F locates the bath
northwest, above the lower powder room, and gives laundry direct circulation access.
Its peninsula replaces the island. Fixture headroom remains an explicit section hold.

**Decision 3 — bedroom west or east?** Whoever gets east gets the morning
sun and the yard; the other room gets the alley side. A gives the yard to
the sofa and dining table (where you spend waking hours — the conventional
answer). B gives it to the bed (quieter, not over the garage door, and the
wardrobe band buffers stair noise — the better answer if you're
noise-sensitive or a morning person). There is no free lunch; pick whose
daylight matters more.

## Sanity numbers to check every iteration against

- Bedroom: ≥ 70 sf, no dimension under 7' (IRC R304); needs an egress
  window (≥ 5.7 sf clear opening, R310) — fine on the west or south.
- Queen bed = 5'-0" × 6'-8"; want ~2' walkway on each open side. A 9'-8"
  wide bedroom holds a queen + nightstands with room to spare.
- Stair: 3'-0" wide min; Virginia allows 8¼" risers / 9" treads, so the
  8'-9" rise from the +0.5 ft lower slab to the +9.25 ft upper floor
  uses 14 risers at 7.5 in and 13 treads at about 10.15 in plus the landing.
- Kitchen: 36" aisle min (42" nicer); a 10' run + short return comfortably
  holds fridge / sink / range / dishwasher.
- Bath: 36" × 36" shower, 30" width at the toilet, ~22" clear in front of
  the vanity. The 36 sf bath here is tight-but-normal ADU scale.
- Ceilings: habitable rooms want 7'-0"+ (sloped-ceiling allowances exist,
  R305) — this is where the 20 ft height cap bites; resolve it with the
  architect early.

*(Code cites are Virginia Residential Code / IRC as research pointers, not
legal advice — confirm with Richmond building review.)*

## How to iterate

1. Look at a sheet and argue with it ("dining should be by the south
   window", "swap the sofa and table"). For Option F, change shared walls, openings and furniture in
   `model/option_f_geometry.py`; drawing symbols live in `generate_floorplans.py` —
   coordinates are in feet from the SW corner, X east, Y north.
2. Edit, re-run, re-look. The furniture is the test: if the queen bed,
   sofa, and a 4-seat table don't fit with walkways, the scheme fails no
   matter how nice the diagram looks.
3. For current coordination, use the Option F sheet plus
   `plan/site-plan-option-f.dxf` and the construction/engineering basis set.
   Historical studies can still frame trade-offs, but they do not govern the handoff.

Open questions to resolve next: floor-to-floor height vs the 20 ft cap
(drives stair length and ceiling slopes); mini-split head locations;
whether the flex/office corner of the garage gets conditioned from day one.

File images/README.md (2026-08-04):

# Reference imagery

All pictures shared while planning the ADU, in roughly the order they were provided.

| File | What it is |
|---|---|
| `01-handdrawn-siteplan-whole-lot.png` | Owner's hand sketch, whole lot @ 1:192 (¼" = 4 ft) |
| `02-handdrawn-siteplan-back-half.png` | Owner's hand sketch, back half @ 1:96 (¼" = 2 ft) |
| `03-handdrawn-siteplan-back-30ft.png` | Owner's hand sketch, back 30 ft @ 1:48 (¼" = 1 ft) |
| `04-assessor-building-sketch.png` | County assessor building sketch (actDataScout, PID 43615): house footprint dims |
| `05-house-shape-comparison.png` | Owner's hand outline of the actual house shape vs. the assessor sketch |
| `06-satellite-parcel-outline.png` | Aerial with the green parcel boundary drawn |
| `07-satellite-oblique-3d.png` | Oblique 3D aerial (houses 108 / 112 / 114 labeled) |
| `08-satellite-apple-scalebar.png` | Apple Maps aerial with a 0–39 ft scale bar |
| `09-backyard-shed-facing-west.jpg` | Existing shed and west/alley side of the yard |
| `10-backyard-garden-facing-north.jpg` | Existing garden and north side of the yard |
| `11-backyard-alley-parking-facing-east.jpg` | Alley parking and east-facing site context |
| `12-handdrawn-two-level-design-basis.jpg` | Owner's preferred two-level layout sketch; design basis for floor-plan Option E |
| `13-option-f-construction-set-cover.png` | Cover preview of the current Option F construction and engineering basis set |
| [`../documents/assessor-building-sketch-43615.pdf`](../documents/assessor-building-sketch-43615.pdf) | Canonical original assessor PDF (source of #04); a legacy byte-identical copy remains in this folder |

Notes:
- The original hand-drawn `site plans.pdf` (~57 MB phone photos) remains outside the repository;
  pages 1–3 are captured as PNGs #01–03 above and as a compressed PDF in `documents/`.
- Assessor sketch shows the shed as "OB02 360 sf" (18×20); owner says that is **not** accurately
  measured — use **12 × 18**.

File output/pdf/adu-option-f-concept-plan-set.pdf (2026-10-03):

## SITE / SEPTEMBER 2026

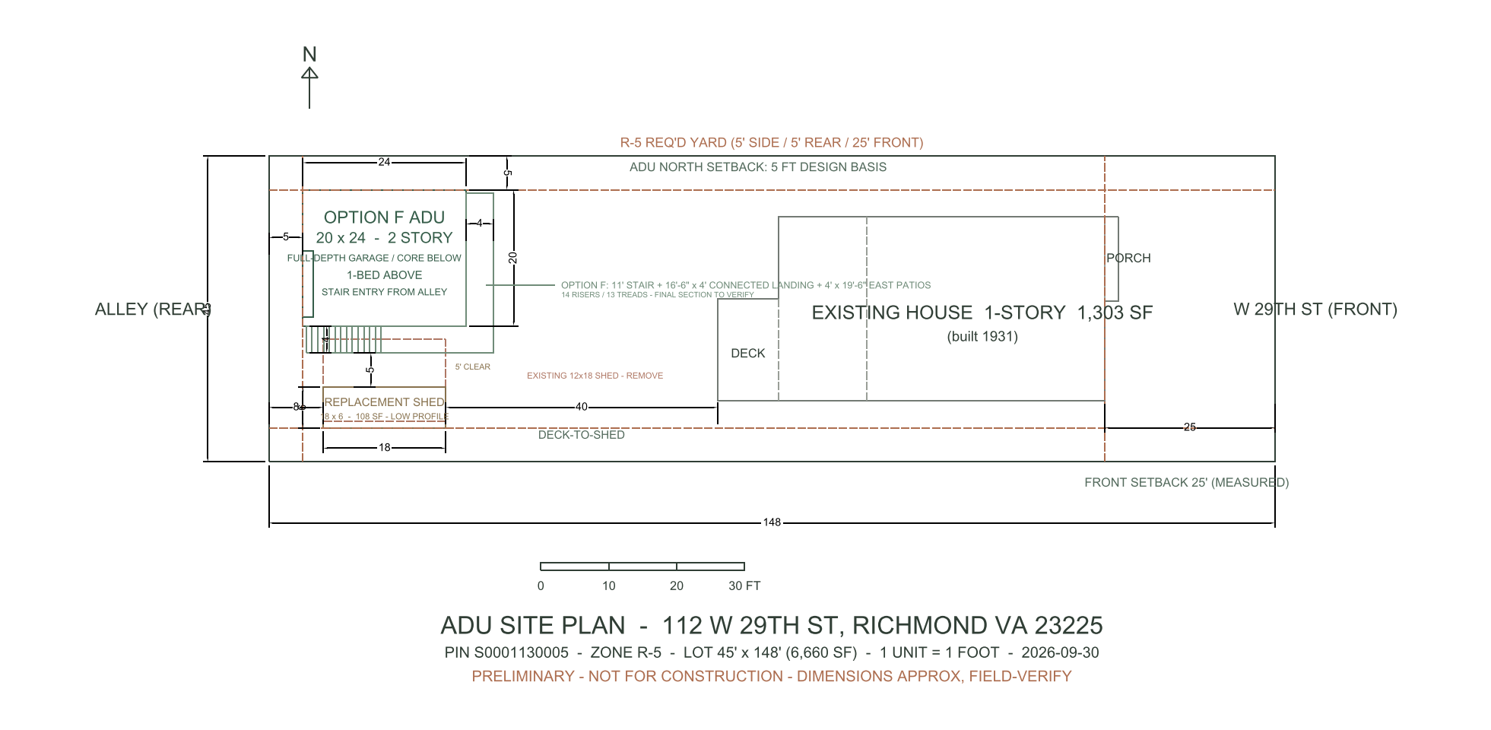
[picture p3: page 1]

Owner design study. Not for construction. Final structure, headroom, vehicle fit and zoning remain unresolved. | 1 / 4

## LEVEL 1 / REVISED OPTION F

Owner design study. Not for construction. Final structure, headroom, vehicle fit and zoning remain unresolved. | 2 / 4

## LEVEL 2 / REVISED OPTION F

Owner design study. Not for construction. Final structure, headroom, vehicle fit and zoning remain unresolved. | 3 / 4

## EXPLORATORY GARDEN-ROOM ALTERNATIVE

Owner design study. Not for construction. Final structure, headroom, vehicle fit and zoning remain unresolved. | 4 / 4

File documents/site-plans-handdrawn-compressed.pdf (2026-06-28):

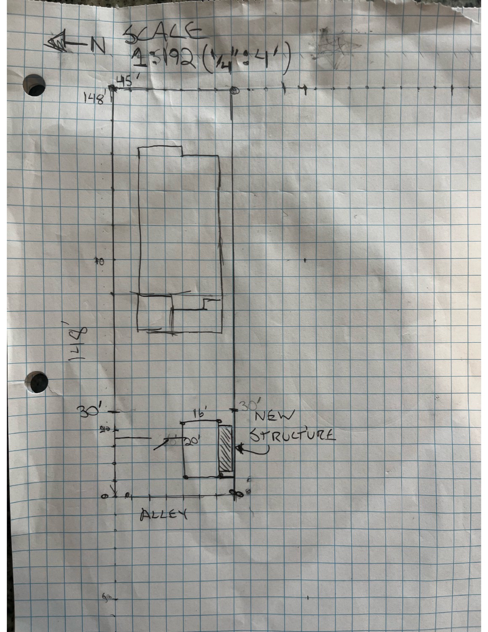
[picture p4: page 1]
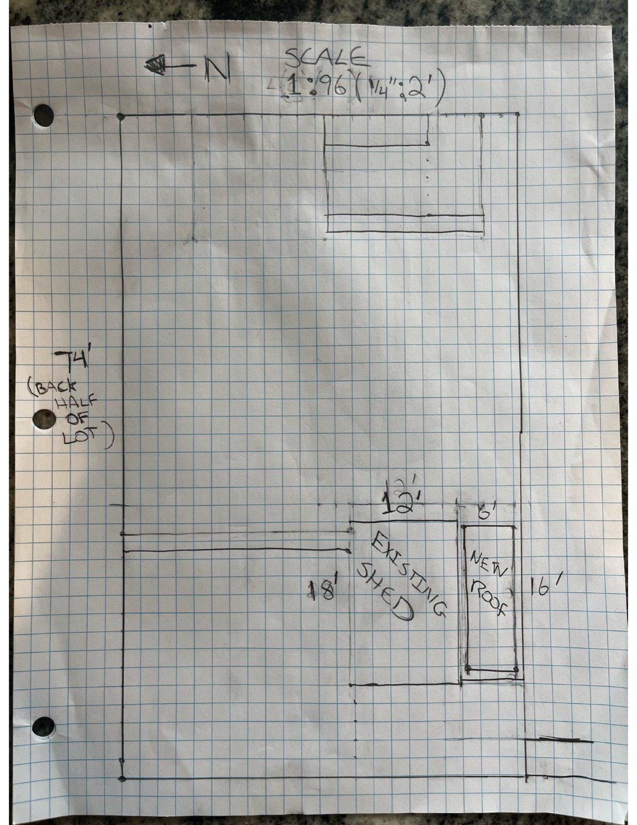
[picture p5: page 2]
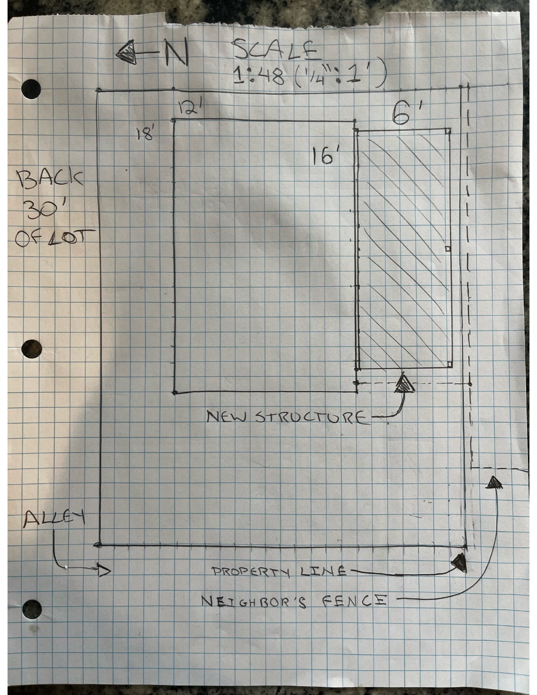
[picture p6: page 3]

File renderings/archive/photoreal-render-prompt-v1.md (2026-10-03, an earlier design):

> Historical prompt brief, superseded by Option F revision 2 on September 30, 2026. Paths below were relative to the original renderings directory. Do not use its layout or datum statements for new images.

# Option F ADU image-generation prompts

Updated for the current Option F floor and site plans. These prompts supersede geometry inferred from Option E models and all earlier renders.

## Source hierarchy

Use sources in this order when they conflict:

1. `../apartment/option-f-recommended-development.png` — current rooms, openings, stair, landing, patios, and circulation
2. `../plan/site-plan-option-f.png` — current placement, setbacks, exterior access, patio depth, and replacement shed
3. `../plan/site-plan-option-f.dxf` — true-scale site geometry
4. `../inspiration/03-craftsman-gray-red-trim-carriage-door.jpg` — exterior style and materials only
5. actual `../images/` photographs — vegetation, fences, alley, and yard character
6. `../model/adu-option-f.step` and `../model/adu-option-f.glb` — current coordinated Option F three-dimensional geometry
7. Option E CAD/axonometric files — historical comparison only; never use their doors, windows, patio depth, room program, access geometry, or vertical datums

Earlier generated renders are not geometry references. In particular, do not restore Option E's first-floor shower, downstairs laundry, smaller sliders, separate office door, 3-ft-6-in patio depth, or a landing that stops before the east patio.

## Prompt 1 — shared master prompt

Use this prompt as the base for either exterior camera block.

```text
Use case: sketch-to-render
Asset type: photorealistic exterior architectural visualization

REFERENCE ROLES
The Option F floor plan is authoritative for room adjacencies, exterior openings, stair, landing, patios, and doors. The Option F site plan controls placement, setbacks, circulation, patio depth, and replacement-shed placement. The Craftsman reference controls style and materials. Actual site photographs control the Richmond alley, garden, vegetation, and weathered context. Option E files may inform general gable massing only and never override Option F geometry.

PRIMARY REQUEST
Create a convincing photograph of the proposed detached Option F ADU at 112 W 29th St in Richmond, Virginia. It must feel specifically designed for this compact, informal backyard rather than like a generic suburban new build.

BUILDING MASSING
- Enclosed footprint: exactly 24 feet east-west by 20 feet north-south, 480 square feet gross per level.
- Exactly two stories: full-depth garage, support space, powder room, protected hall, and owner office/garden room below; one-bedroom apartment above.
- Working top-of-upper-subfloor elevation: 9 feet 3 inches above the level-1 slab datum.
- East-west gable ridge: 16-foot eaves and a 19-foot-10-inch maximum ridge basis, with west alley and east yard elevations as gable ends.
- Low-pitch dark-charcoal composition-shingle roof. No shed roof, flat roof, or dormers.
- ADU sits 5 feet east of the west alley property line and 5 feet south of the north property line.
- Keep the west rake and north eave flush to the setback walls. Add projections there only after zoning approval or inward relocation of the building.

STYLE AND MATERIALS
- muted sage or gray-green horizontal wood lap siding
- warm creamy-white corner boards, fascia, posts, stair structure, landing structure, and traditional painted wood guards
- muted barn-red window sashes and selected doors
- divided-light windows, restrained projections where allowed, exposed painted rafter tails, restrained Craftsman knee braces, and a small gable vent
- black traditional lantern sconces
- cream carriage-style garage door with square top-row windows and black hardware
- real wood stair treads and decking
- believable texture and slight weathering; refined but not pristine

EXACT SOUTH STAIR AND CONNECTED LANDING — HIGHEST PRIORITY
- One straight exterior stair flight is attached parallel to the outside of the south wall.
- Stair is 4 feet wide, has 14 risers and 13 treads, and has an 11-foot horizontal run.
- It starts at grade at the southwest alley end and rises west-to-east.
- The stair occupies only the western 11 feet. Do not stretch stair treads across the entire south wall.
- At the top, all treads stop and a flat, raised, 4-foot-deep landing continues east along the south wall.
- A separate conventional hinged apartment-entry door opens from this landing into the upper south wall.
- The landing passes the entry, wraps around the southeast corner, and connects openly to the upper east patio. Do not end it at a small square platform or place a guard across the patio connection.
- Stair, flat landing, corner turn, and east patio form one continuous L-shaped circulation route.

STACKED EAST PATIOS AND LARGE SLIDERS
- Ground east patio: exactly 4 feet deep by approximately 19 feet 6 inches long, running almost the full south-to-north east wall.
- Upper east patio: the same 4-foot by 19-foot-6-inch footprint, stacked directly above the ground patio on painted Craftsman posts.
- Keep the upper patio narrow and full-length; do not turn it into an oversized deep deck.
- Upper level: one large 6-foot sliding-glass door near the south end, opening from the living room directly to the upper patio.
- Lower level: one large 6-foot sliding-glass door near the north end, opening from the owner office/garden room directly to the ground patio.
- Include restrained kitchen/dining glazing farther north on the upper east wall where compatible.
- Do not invent a separate exterior office door and do not replace either slider with a small hinged door or ordinary window.

COVERED LOWER SOUTH PATIO
- The raised flat south landing shelters the lower south patio; do not invent a separate roof or canopy.
- The lower south patio continues openly around the southeast corner into the ground east patio.
- Keep the stair flight itself open to the sky.

INTERIOR INTENT
- Level 1 has a powder room only, with no shower.
- Washer/dryer is upstairs in the northwest low-eave seasonal-storage room beside the stacked bath, not downstairs.
- The lower northeast room is an owner office/garden room, not a bedroom or independent dwelling unit.
- Upper southeast is open living; kitchen and dining occupy the east/north side.

REPLACEMENT SHED AND SITE
- Remove the old 12-by-18-foot corrugated shed from the scene.
- Show a low-profile replacement shed: 18 feet east-west by 6 feet north-south, maximum 108-square-foot outer envelope.
- Keep a clearly usable 5-foot circulation, drainage, and maintenance strip between shed and stair.
- Replacement shed has approximately 7-foot eaves, a 9-foot-6-inch ridge, and a muted red sliding door on its east gable end.
- Use actual Richmond backyard character: mature deciduous trees, lush informal garden beds, weathered wood fencing, gravel alley and parking surface, and humid Virginia greenery.

PHOTOGRAPHY
Photorealistic architectural photography, eye level, 28-35 mm lens, natural proportions, soft overcast Richmond daylight, restrained dynamic range, realistic shadows, slight material imperfections, and sharp architectural detail.

CONSTRAINTS
Exactly two stories. No third story, shed roof, flat roof, dormers, separate roof over landing/stair, spiral or switchback stair, stair on east facade, stair treads along the flat landing, guard blocking the southeast connection, oversized wraparound deck, black industrial railing, garage door on east/south, separate exterior office door, old tall shed, cars, people, labels, arrows, dimensions, signs, logos, or watermark.
```

## Prompt 2 — alley-side camera block

Append this block to Prompt 1.

```text
CAMERA — ALLEY-SIDE VIEW
Camera stands in the west alley, slightly southwest of the ADU, looking northeast. The west gable and garage elevation are primary. Frame enough of the south wall and east end to prove the complete access sequence.

Show one cream carriage-style garage door at level 1 and exactly one generous upper west bedroom EERO casement. Keep the west gable rake flush. South is camera-right. Near the camera, the 4-foot-wide stair rises away from the alley for its 11-foot run. At the top, treads stop and the long flat landing continues past the conventional upper entry and five-foot-wide raised-sill living window, then wraps openly around the southeast corner. There is no south-wall slider. Reveal enough of the stacked east patios and their two large sliders to make that connection legible.

Show the low 18-by-6-foot replacement shed south of the stair, not the old tall shed. Keep a visible 5-foot clear strip between shed and stair. Do not make the stair climb across the west garage facade, continue treads along the landing, or hide circulation beneath an invented stair roof.
```

Reference bundle:

1. `../apartment/option-f-recommended-development.png`
2. `../plan/site-plan-option-f.png`
3. `../inspiration/03-craftsman-gray-red-trim-carriage-door.jpg`
4. `../images/11-backyard-alley-parking-facing-east.jpg`

Current generated output: `option-f-alley-photoreal-v2.png`

## Prompt 3 — yard-side camera block

Append this block to Prompt 1.

```text
CAMERA — YARD-SIDE VIEW
Camera stands southeast of the ADU in the east yard, looking northwest at the southeast corner. The east gable and stacked patios are primary; the south wall and exterior stair recede on camera-left. Use a wide eye-level three-quarter composition that keeps both patios, both sliders, the flat landing, and the stair visible.

Show the upper and ground east patios at the same 4-foot by 19-foot-6-inch footprint. Clearly show the upper 6-foot living-room slider near the south end and lower 6-foot owner-room slider near the north end. The two sliders are separate openings serving different rooms. Include restrained upper kitchen/dining glazing farther north. Retain the conventional hinged apartment-entry door on the south landing and do not invent a separate exterior office door.

On camera-left, show the stair running along the south wall from southwest grade. Treads end after the 11-foot flight. The flat raised landing continues to the southeast corner, where it turns 90 degrees into the upper east patio with no guard across the opening. The landing shelters the lower south patio, which also connects openly to the ground east patio.

The low replacement shed may appear at the south edge of frame but must not block the stair, landing, or corner connection. Do not put stair treads across the east facade or long landing, reduce the landing to a small square, create a detached platform, or add an extra roof.
```

Reference bundle:

1. `../apartment/option-f-recommended-development.png`
2. `../plan/site-plan-option-f.png`
3. `../inspiration/03-craftsman-gray-red-trim-carriage-door.jpg`
4. `../images/10-backyard-garden-facing-north.jpg`

Current generated output: `option-f-yard-photoreal-v2.png`

## Remaining design caveat

The renderings communicate intent, not construction geometry. Before further render refinement, an architect and structural engineer should resolve the exact stair/guard section, clear patio width after guards, posts and lateral bracing, drainage/flashing, roof headroom, opening headers, and garage fire separation. Update the reference plans before regenerating images whenever those decisions change.

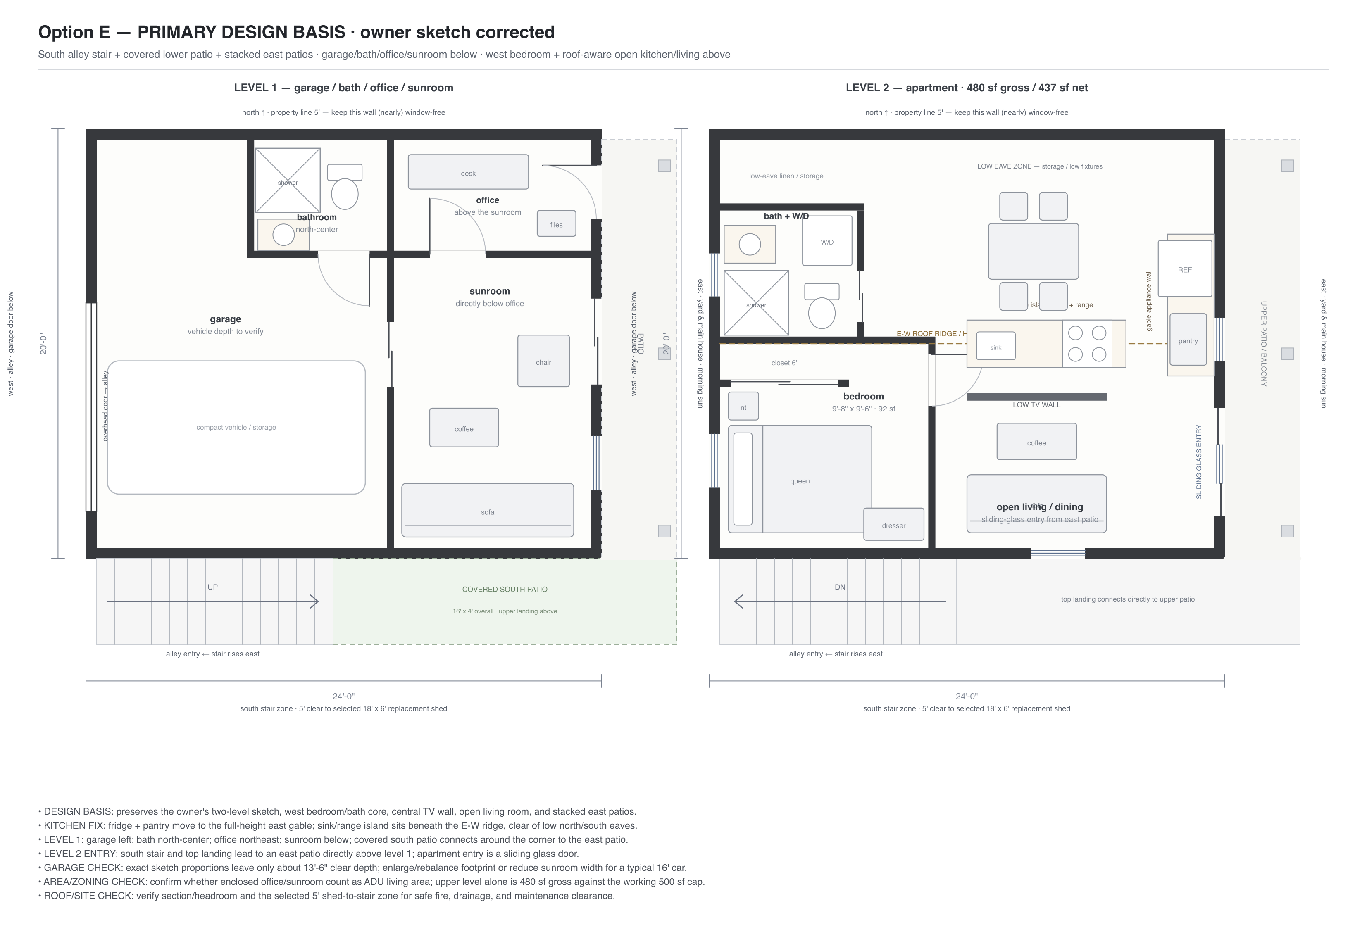
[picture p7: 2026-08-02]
apartment/option-e-primary-design-basis.png

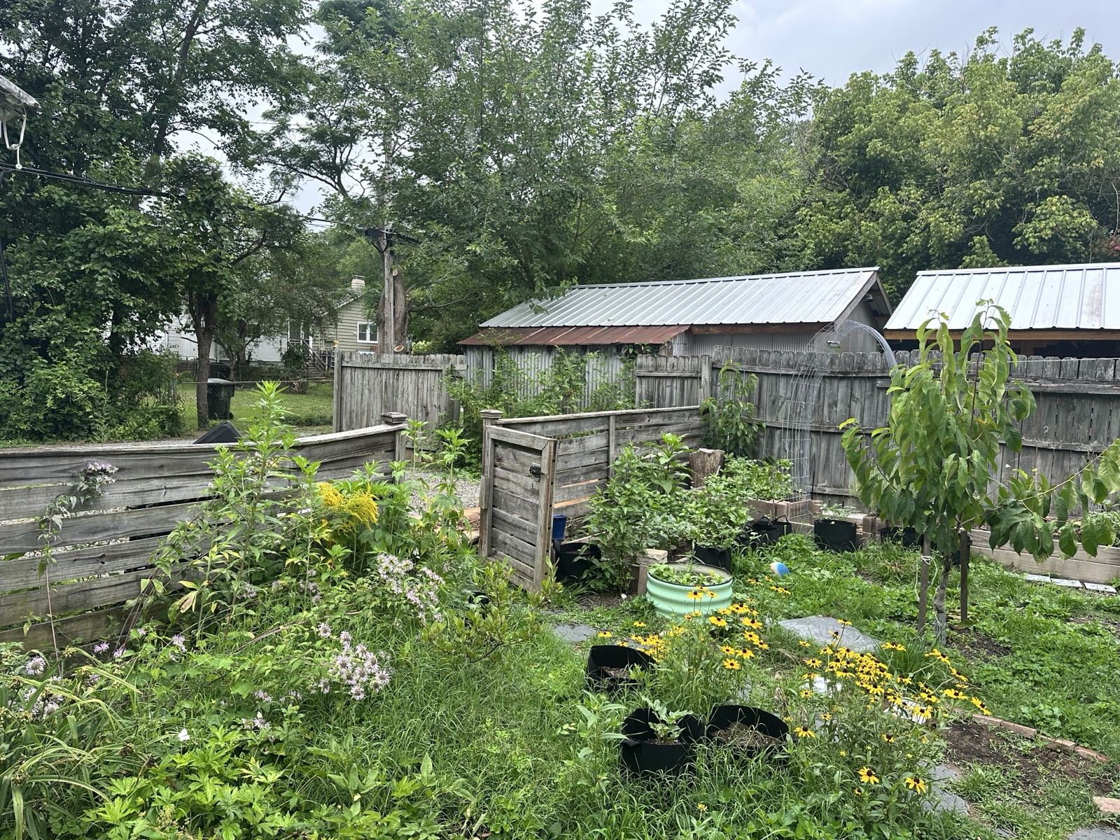
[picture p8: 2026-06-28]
images/10-backyard-garden-facing-north.jpg

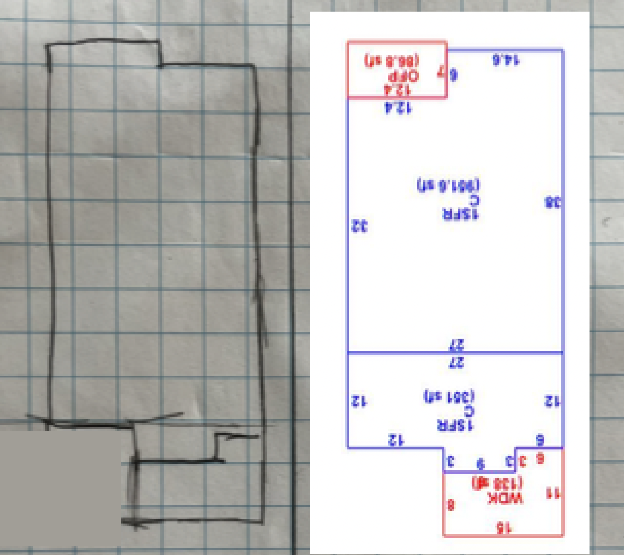
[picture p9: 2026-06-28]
images/05-house-shape-comparison.png

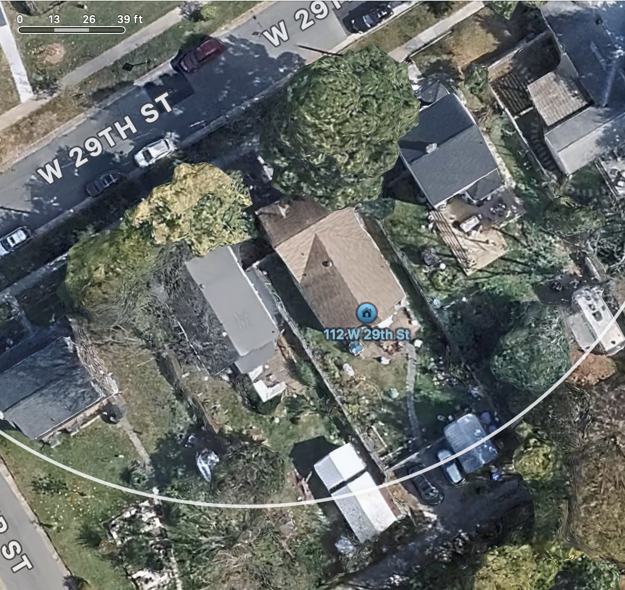
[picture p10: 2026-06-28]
images/08-satellite-apple-scalebar.png

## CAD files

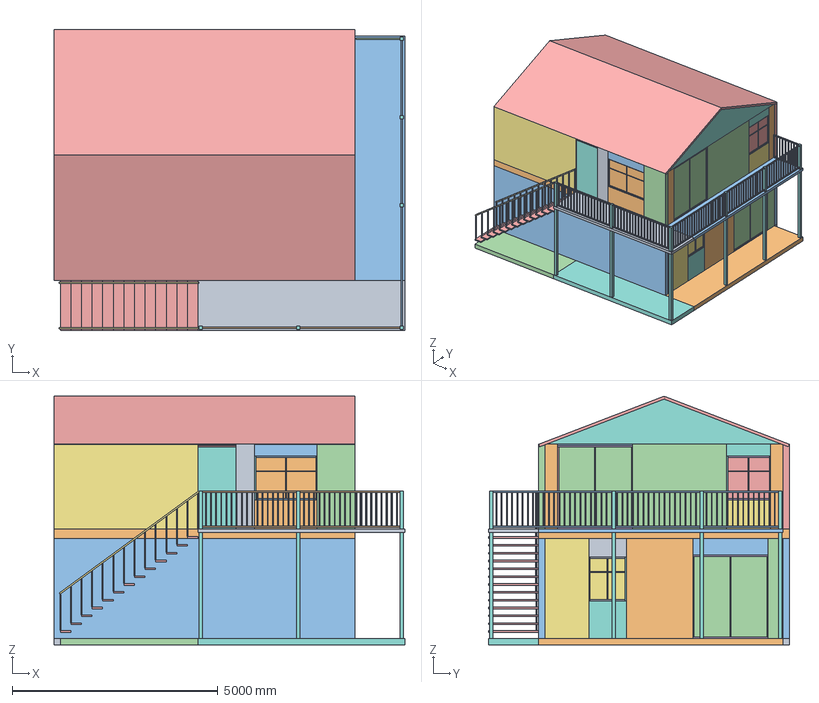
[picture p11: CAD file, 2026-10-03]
model/adu-option-f.step
8534.4 x 7315.2 x 6045.2 mm

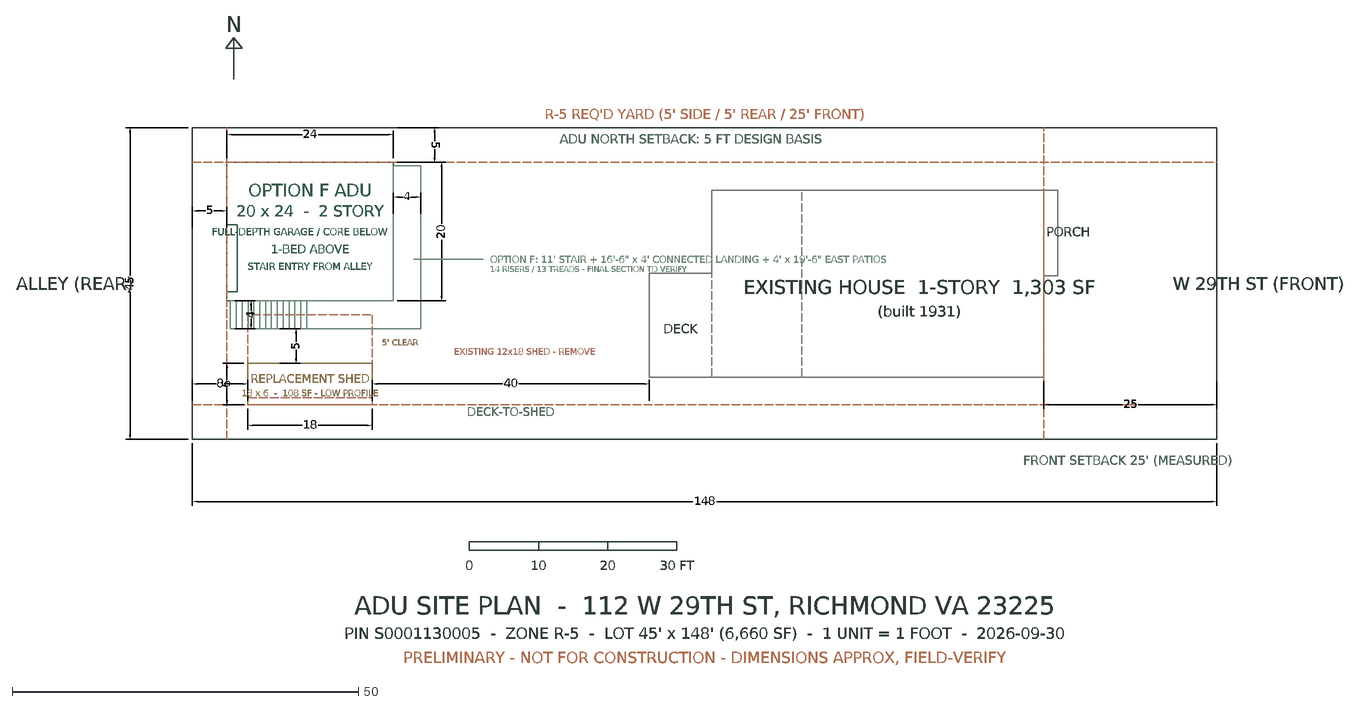
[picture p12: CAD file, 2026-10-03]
plan/site-plan-option-f.dxf
148
45
18
6
8
5
24
20
4
25
40
EXISTING HOUSE 1-STORY 1,303 SF
(built 1931)
PORCH
DECK
EXISTING 12x18 SHED - REMOVE
REPLACEMENT SHED
18 x 6 - 108 SF - LOW PROFILE
OPTION F ADU
20 x 24 - 2 STORY
FULL-DEPTH GARAGE / CORE BELOW
1-BED ABOVE
STAIR ENTRY FROM ALLEY
OPTION F: 11' STAIR + 16'-6" x 4' CONNECTED LANDING + 4' x 19'-6" EAST PATIOS
14 RISERS / 13 TREADS - FINAL SECTION TO VERIFY
5' CLEAR
ALLEY (REAR)
W 29TH ST (FRONT)
R-5 REQ'D YARD (5' SIDE / 5' REAR / 25' FRONT)
ADU NORTH SETBACK: 5 FT DESIGN BASIS
FRONT SETBACK 25' (MEASURED)
DECK-TO-SHED
N
0
10
30 FT
ADU SITE PLAN - 112 W 29TH ST, RICHMOND VA 23225
PIN S0001130005 - ZONE R-5 - LOT 45' x 148' (6,660 SF) - 1 UNIT = 1 FOOT - 2026-09-30
PRELIMINARY - NOT FOR CONSTRUCTION - DIMENSIONS APPROX, FIELD-VERIFY

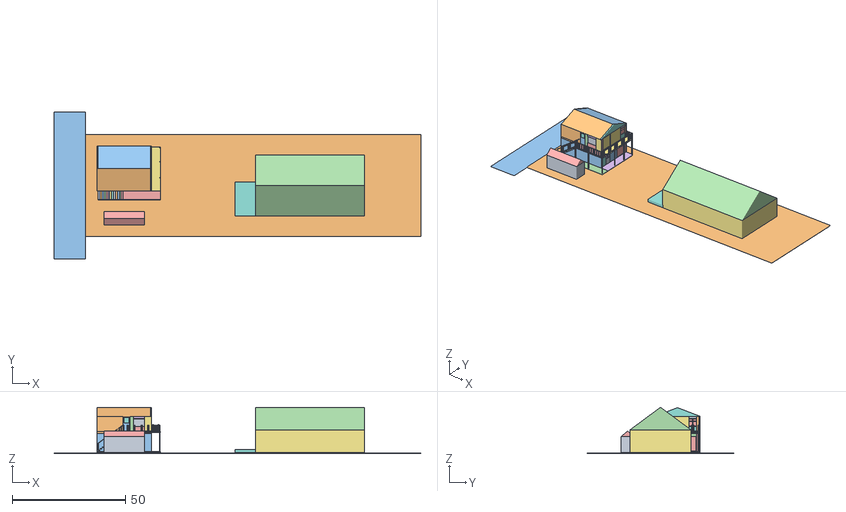
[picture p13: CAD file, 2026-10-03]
model/site-model.obj
162.0 x 65.0 x 20.5
geometry_0
geometry_1
geometry_2
geometry_3
geometry_4
geometry_5
geometry_6
geometry_7
geometry_8
geometry_9
geometry_10
geometry_11
geometry_12
geometry_13
geometry_14
geometry_15
geometry_16
geometry_17
geometry_18
geometry_19
geometry_20
geometry_21
geometry_22
geometry_23
geometry_24
geometry_25
geometry_26
geometry_27
geometry_28
geometry_29
geometry_30
geometry_31
geometry_32
geometry_33
geometry_34
geometry_35
geometry_36
geometry_37
geometry_38
geometry_39
geometry_40
geometry_41
geometry_42
geometry_43
geometry_44
geometry_45
geometry_46
geometry_47
geometry_48
geometry_49
geometry_50
geometry_51
geometry_52
geometry_53
geometry_54
geometry_55
geometry_56
geometry_57
geometry_58
geometry_59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

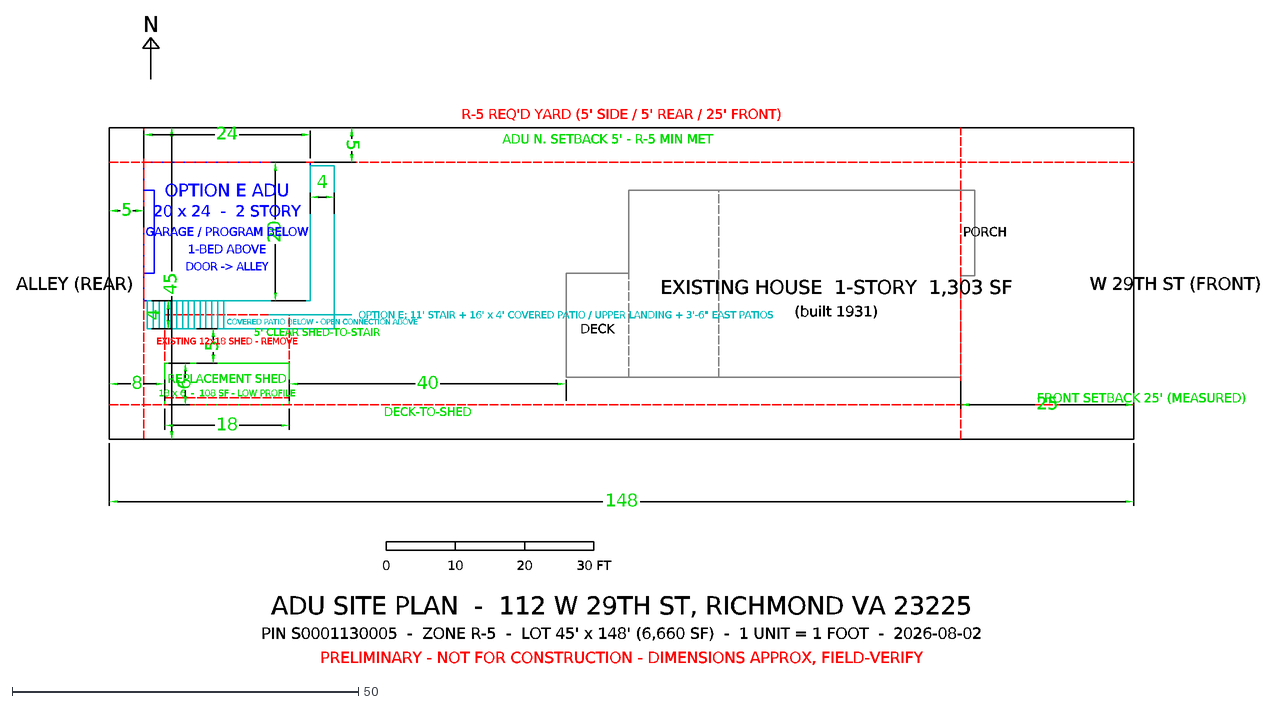
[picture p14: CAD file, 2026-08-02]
plan/site-plan.dxf
148
45
18
6
8
5
24
20
4
25
40
EXISTING HOUSE 1-STORY 1,303 SF
(built 1931)
PORCH
DECK
EXISTING 12x18 SHED - REMOVE
REPLACEMENT SHED
18 x 6 - 108 SF - LOW PROFILE
OPTION E ADU
20 x 24 - 2 STORY
GARAGE / PROGRAM BELOW
1-BED ABOVE
DOOR -> ALLEY
OPTION E: 11' STAIR + 16' x 4' COVERED PATIO / UPPER LANDING + 3'-6" EAST PATIOS
COVERED PATIO BELOW - OPEN CONNECTION ABOVE
5' CLEAR SHED-TO-STAIR
ALLEY (REAR)
W 29TH ST (FRONT)
R-5 REQ'D YARD (5' SIDE / 5' REAR / 25' FRONT)
ADU N. SETBACK 5' - R-5 MIN MET
FRONT SETBACK 25' (MEASURED)
DECK-TO-SHED
N
0
10
30 FT
ADU SITE PLAN - 112 W 29TH ST, RICHMOND VA 23225
PIN S0001130005 - ZONE R-5 - LOT 45' x 148' (6,660 SF) - 1 UNIT = 1 FOOT - 2026-08-02
PRELIMINARY - NOT FOR CONSTRUCTION - DIMENSIONS APPROX, FIELD-VERIFY

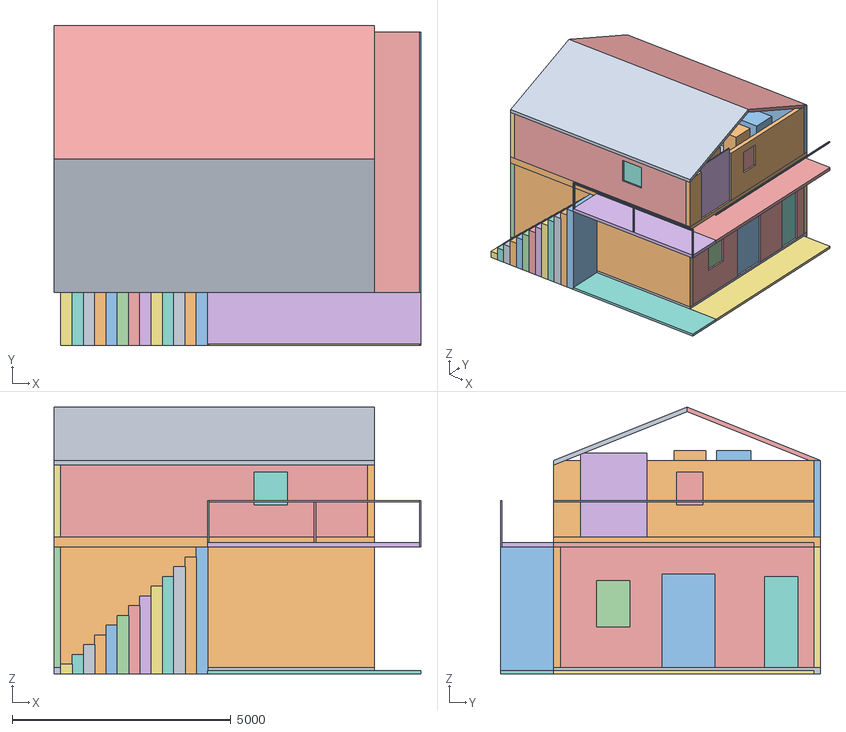
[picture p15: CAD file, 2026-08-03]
model/adu-option-e-arch.obj
8382.0 x 7315.2 x 6096.0
Bathroom and laundry
Bedroom
East balcony guard rail
East gable appliance run
East kitchen window
East sliding glass entry
Exterior stair step 01
Exterior stair step 02
Exterior stair step 03
Exterior stair step 04
Exterior stair step 05
Exterior stair step 06
Exterior stair step 07
Exterior stair step 08
Exterior stair step 09
Exterior stair step 10
Exterior stair step 11
Exterior stair step 12
Exterior stair step 13
Garage and storage zone
Garage north return
Garage overhead door
Ground east patio
Ground south covered patio
Kitchen and dining
Kitchen ridge island
L1 bathroom south wall
L1 bathroom west wall
L1 east exterior wall
L1 garage to east rooms
L1 north exterior wall
L1 office south wall
L1 shower
L1 south exterior wall
L1 vanity
L1 west exterior wall with garage door
L2 bath east wall
L2 bath storage wall
L2 bedroom closet wall
L2 bedroom east wall
L2 bedroom north wall
L2 east exterior wall
L2 north blank exterior wall
L2 shower
L2 south exterior wall
L2 vanity
L2 west exterior wall
Level 1 bathroom
Level 1 slab 20x24
Level 2 floor assembly 20x24
Low TV wall
Low eave linen storage
North roof plane
Office
Office desk
Office east door
Open living and dining
Pantry
Refrigerator
South landing guard post 11.5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

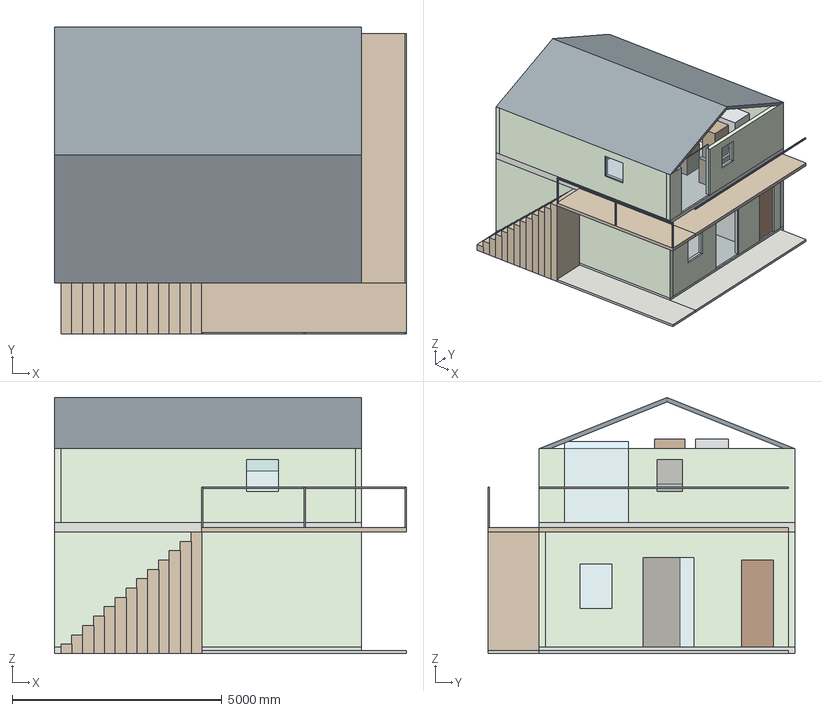
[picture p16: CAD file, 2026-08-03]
model/adu-option-e.step
8382.0 x 7315.2 x 6096.0 mm
Bathroom and laundry
Bedroom
East balcony guard rail
East gable appliance run
East kitchen window
East sliding glass entry
Exterior stair step 01
Exterior stair step 02
Exterior stair step 03
Exterior stair step 04
Exterior stair step 05
Exterior stair step 06
Exterior stair step 07
Exterior stair step 08
Exterior stair step 09
Exterior stair step 10
Exterior stair step 11
Exterior stair step 12
Exterior stair step 13
Garage and storage zone
Garage north return
Garage overhead door
Ground east patio
Ground south covered patio
Kitchen and dining
Kitchen ridge island
L1 bathroom south wall
L1 bathroom west wall
L1 east exterior wall
L1 garage to east rooms
L1 north exterior wall
L1 office south wall
L1 shower
L1 south exterior wall
L1 vanity
L1 west exterior wall with garage door
L2 bath east wall
L2 bath storage wall
L2 bedroom closet wall
L2 bedroom east wall
L2 bedroom north wall
L2 east exterior wall
L2 north blank exterior wall
L2 shower
L2 south exterior wall
L2 vanity
L2 west exterior wall
Level 1 bathroom
Level 1 slab 20x24
Level 2 floor assembly 20x24
Low TV wall
Low eave linen storage
North roof plane
Office
Office desk
Office east door
Open living and dining
Pantry
Refrigerator
South landing guard post 11.5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

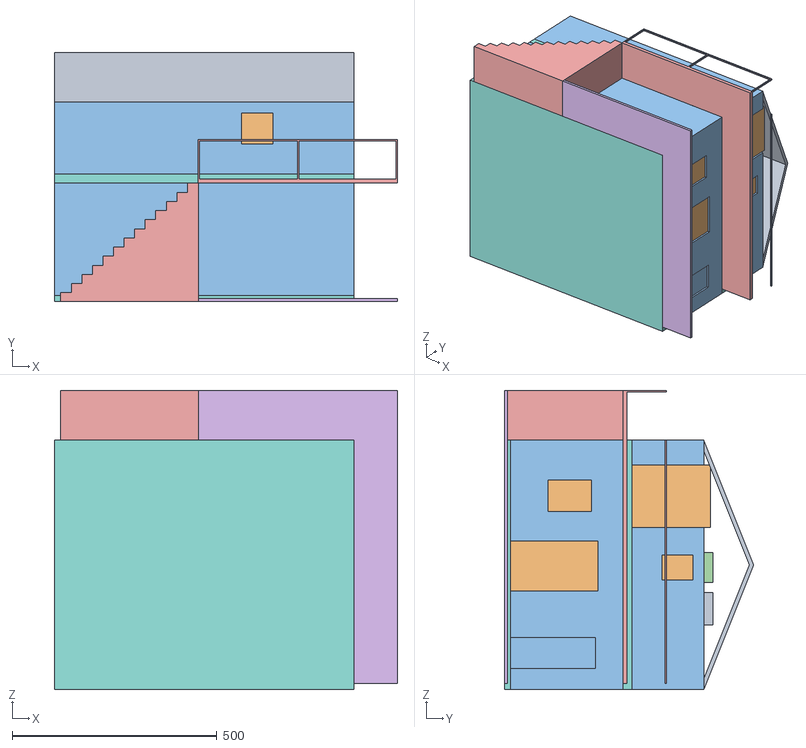
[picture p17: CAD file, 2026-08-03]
model/adu-option-e-sweethome.obj
838.2 x 609.6 x 731.5
color_475761
color_59b3e0
color_7a4d2b
color_94734f
color_a38c6b
color_adb0a6
color_b0ccf0
color_b8b8b3
color_b8bdbf
color_b8e3d1
color_bdd1b3
color_ccc2e6
color_d1d1c7
color_ebe6d6
color_ebf0f2
color_f5bdb3
color_f5c7b8
color_f5dba6

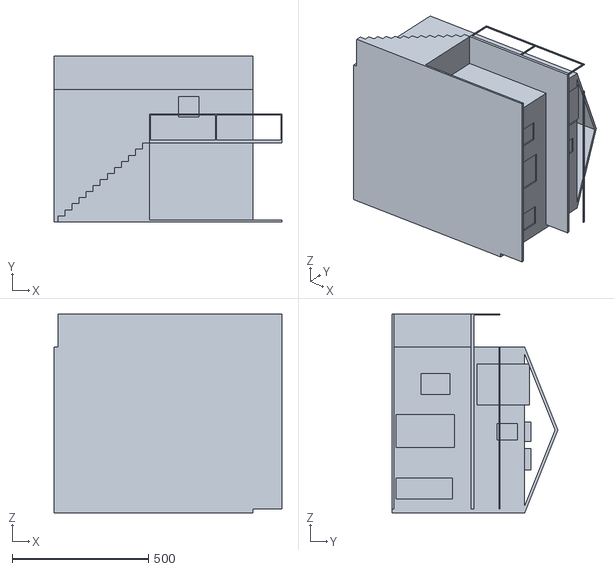
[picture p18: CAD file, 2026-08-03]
model/adu-option-e-sweethome-simple.obj
838.2 x 609.6 x 731.5

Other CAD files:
model/adu-option-e.FCStd
model/adu-option-e.obj
model/adu-option-f.obj

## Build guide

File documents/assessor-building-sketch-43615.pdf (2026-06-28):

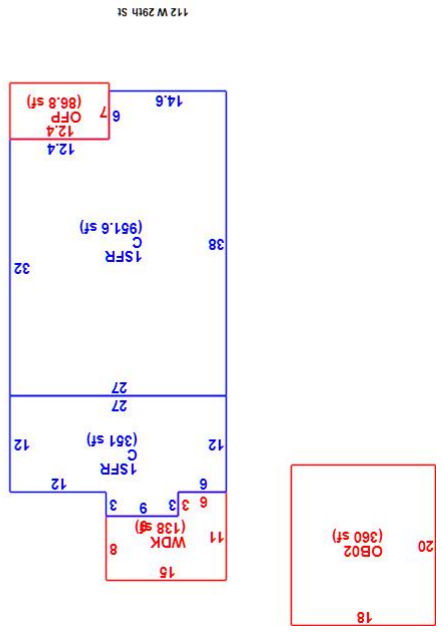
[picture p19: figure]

43615 PID:

Page 1 www.actDataScout.com Subject to terms and conditions.
Not a Legal Document.

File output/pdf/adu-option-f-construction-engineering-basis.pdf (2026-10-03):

### OPTION F DETACHED ADU - 112 W 29TH ST, RICHMOND, VA 23225

REV 2 OWNER STUDY - NOT FOR CONSTRUCTION - CODE / ENGINEERING CRITERIA REQUIRE PROFESSIONAL RECONFIRMATION

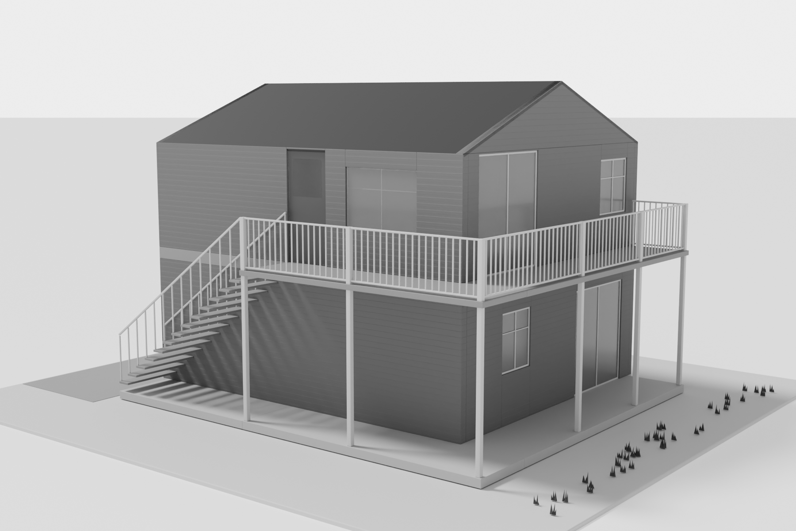
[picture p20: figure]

COVER / PROJECT BASIS
ISSUE 2026-09-30 | DRAWN FOR OWNER COORDINATION | G001
G001 COVER / PROJECT BASIS | OPTION F / 20 FT x 24 FT / 480 SF UPPER ADU

# OPTION F DETACHED ADU

# CONSTRUCTION / ENGINEERING BASIS SET

## 112 W 29TH ST, RICHMOND, VA 23225 PIN S0001130005 | ZONE R-5 | 20 FT x 24 FT

## SCHEMATIC - NOT FOR CONSTRUCTION

Prepared from owner sketches, field measurements, assessor documents, repo CAD/model geometry, and Option F coordination. Licensed architect/engineer must verify and complete before permit or construction.

SHARED GEOMETRY / REVISION 2 - SCHEMATIC OWNER DESIGN STUDY

BASIS AND LIMITS

1. Enclosed building: 24 ft east-west x 20 ft north-south; two stories; 480 sf gross upper ADU. Exterior stair and east patios remain unenclosed.
2. Selected Option F: full-depth south garage, stacked northwest wet core, northeast owner flex room, west bedroom, east living/kitchen, south stair, and east patios.
3. No survey, utility locate, geotechnical report, drainage design, truss package, engineered lumber calculations, REScheck, HVAC Manual J/S/D, electrical load calculation, or sealed structural design was available.
4. Do not scale drawings. Dimensions are design-basis values. Field verify property lines, grades, utilities, existing house geometry, and all product rough openings.
5. North and west roof edges are flush at setback walls in this basis. Any eave/rake projection requires Zoning confirmation or inward relocation of building.
6. This set coordinates decisions and exposes missing work. It is not permission to build and carries no professional seal.
SHEET | TITLE | STATUS | PRIMARY COMPLETION NEED
G001 | COVER / PROJECT BASIS | BASIS | Architect/engineer verification
G002 | CODE, ZONING, AND PERMIT MATRIX | BASIS | Architect/engineer verification
C101 | SITE / ACCESS / UTILITY CONCEPT | BASIS | Architect/engineer verification
A101 | LEVEL 1 DIMENSIONED PLAN | BASIS | Architect/engineer verification
A102 | LEVEL 2 DIMENSIONED PLAN | BASIS | Architect/engineer verification
A201 | ROOF PLAN / OPENING SCHEDULES | BASIS | Architect/engineer verification
A301 | EXTERIOR ELEVATIONS | BASIS | Architect/engineer verification
A401 | BUILDING SECTIONS / ENVELOPE | BASIS | Architect/engineer verification
S101 | FOUNDATION / FRAMING BASIS | BASIS | Architect/engineer verification
M101 | MEP / ELECTRICAL / LIFE SAFETY BASIS | BASIS | Architect/engineer verification
G003 | SPECIFICATIONS / CLOSEOUT CHECKLIST | BASIS | Architect/engineer verification

CODE, ZONING, AND PERMIT MATRIX
ISSUE 2026-09-30 | DRAWN FOR OWNER COORDINATION | G002
G002 CODE, ZONING, AND PERMIT MATRIX | OPTION F / 20 FT x 24 FT / 480 SF UPPER ADU
ITEM | DESIGN BASIS | SOURCE / ACTION
Governing residential code | 2021 Virginia Residential Code; effective Jan. 18, 2024 | Confirm with Richmond at permit intake
Risk / use | Detached accessory dwelling over private garage; Risk Category II | Final classification by code official
Wind | 115 mph basic design wind speed, Risk Category II | Richmond structural criteria
Ground snow | 20 psf | Richmond structural criteria
Seismic | Design Category B | Richmond structural criteria
Frost | 18 in minimum | Bottom of exterior footing below frost depth
Soil | 1,500 psf assumed only for preliminary sizing | Geotechnical/soil report and field verification required
Energy | Climate Zone 4A working basis; prescriptive path or REScheck | Confirm jurisdictional climate data and final assemblies
Garage separation | 5/8 in Type X at garage ceiling below habitable rooms; protected supports | VRC R302.6; final listed assembly
Bedroom EERO | 5.7 sf net clear; min 20 in width, 24 in height; sill max 44 in | VRC R310; verify selected product
Stair | 4 ft stair zone; 14 risers at 7.5 in from slab; 13 treads at 10.15 in | Field-set from final floor elevation; VRC R311
Guards | 36 in landings; 34-38 in stair handrail; openings under 4 in | VRC R312; verify graspability/load design

ZONING BASIS - WRITTEN CONFIRMATION NEEDED

1. R-5 lot recorded as 45 ft x 148 ft. Working yards: 5 ft side, 5 ft rear, 25 ft front. Current site drawing places ADU walls at north and alley-side minimums.
2. Detached ADU floor area cannot exceed greater of one-third main dwelling or 500 sf. Upper floor is 480 sf gross. Obtain written ruling for lower owner flex room and powder room exclusions.
3. Accessory building height basis is 20 ft maximum. Model ridge is project Z +19.833 ft; survey average adjacent grade and roof finish before determining legal building height.
4. ADU access must satisfy Public Works and Fire. Confirm hydrant within 250 ft, alley access, address visibility, and any WISP needs.
5. Verify lot coverage, easements, historic-district status, tree impacts, and whether replacement shed is reviewed in same zoning application.

PERMIT / DEFERRED SUBMITTAL MATRIX

1. Black-and-white PDF; architectural plans at minimum 1/8 in = 1 ft. Submit site, foundation, framing, floor plans, elevations, sections, insulation, and rated assemblies.
2. Separate trade permits: electrical, plumbing, mechanical, and gas if used. This sheet coordinates scope but is not a trade permit application.
3. Deferred engineered items: roof trusses/rafters, floor trusses or I-joists, LVL/PSL headers, portal frame/hold-downs, exterior stair/deck framing, and any unusual foundation condition.
4. New-home checklist calls for soil report, braced-wall information, truss package, structural reports as applicable, and REScheck or equivalent envelope data.
5. Before excavation: boundary/topographic survey, utility locate (Virginia 811), sanitary invert, water capacity/meter decision, electrical service/load study, drainage path, and erosion/stormwater screening.

Sources checked 2026-08-03: rva.gov/planning-development-review/permits-and-inspections rva.gov/planning-development-review/accessory-dwelling-units rva.gov/sites/default/files/2025-02/Building Plan Requirements Residential 2021 VRC Updated.pdf codes.iccsafe.org/content/VARC2021P1/

SITE / ACCESS / UTILITY CONCEPT
ISSUE 2026-09-30 | DRAWN FOR OWNER COORDINATION | C101
C101 SITE / ACCESS / UTILITY CONCEPT | OPTION F / 20 FT x 24 FT / 480 SF UPPER ADU

EXISTING HOUSE

OPTION F ADU

20 x 24 / 2 STORY

18 x 6 SHED

ELEC / WATER - ROUTE TBD

SANITARY - VERIFY INVERT / FALL
ALLEY | W 29TH ST

N

148'-0"

45'-0"

SITE / GRADING NOTES

1. Survey controls. Do not establish building from fences, aerials, or this diagram. Licensed surveyor to stake walls and verify setbacks before footing excavation.
2. Maintain positive drainage away from new foundation. Working target: 6 in fall within first 10 ft where feasible; civil designer to adapt to lot and prevent discharge onto neighbors or alley.
3. Roof drainage: gutters both eaves, sealed downspouts to approved splash blocks or infiltration system. No discharge across stair, alley, or neighboring property.
4. Limit disturbed area; install stabilized construction entrance, inlet protection if applicable, and perimeter controls required by Water Resources.
5. Protect trees and existing house foundation. Arborist to review roots within excavation zone before final siting.

UTILITY BASIS

1. Water: new 1 in service from approved connection basis; size by developed length and fixture units. Confirm meter/backflow policy with DPU.
2. Sanitary: 4 in building sewer at code slope where gravity route is feasible. Camera/locate existing line and verify invert before foundation design.
3. Electrical: feeder from existing service to detached-building panel; electrician to perform dwelling/service load calculation and grounding design.
4. Communications: separate conduit with pull string. Maintain separation from power and other utilities.
5. No gas planned. All-electric basis uses heat pump HVAC, heat-pump water heater, induction range, and electric dryer.

SITE DIMENSIONS TO VERIFY

1. Lot: 45 ft x 148 ft; main house east wall approx. 25 ft from front line; field/survey confirmation governs.
2. ADU enclosed walls: west x=5 ft; east x=29 ft; south y=20 ft; north y=40 ft in repo coordinates.
3. Replacement shed: 18 ft x 6 ft maximum outside envelope, 8 ft from alley and 5 ft side setback. Keep roof, gutters, and foundation within envelope.
4. Stair/access band: approximately x=5.5 to 33 ft and y=16 to 20 ft; 5 ft clear to replacement shed basis.
5. Existing shed removal must be reconciled with assessor's historical detached-garage record before demolition permit scope is finalized.

LEVEL 1 DIMENSIONED PLAN
ISSUE 2026-09-30 | DRAWN FOR OWNER COORDINATION | A101
A101 LEVEL 1 DIMENSIONED PLAN | OPTION F / 20 FT x 24 FT / 480 SF UPPER ADU

PLAN NOTES

1. Garage floor: 4 in concrete slab over compacted granular base and 10 mil vapor retarder; slope only where approved and coordinate overhead-door threshold.
2. Separate garage from upper dwelling with listed floor/ceiling assembly using minimum 5/8 in Type X gypsum at garage ceiling. Protect supporting walls/columns and seal penetrations.
3. Door from garage to protected hall: self-closing/self-latching 20-minute or 1-3/8 in solid wood/steel as accepted; no direct opening into sleeping room.
4. Mechanical/storage zone is unconditioned unless final energy design encloses equipment. HPWH condensate and pan drain require approved termination.
5. Owner flex-room zoning classification controls finishes, heating/cooling, and whether lower area counts toward ADU cap. Do not construct as sleeping room.
6. Overhead door final size: 9 ft 8 in rough planning width. Engineer portal frame/header and manufacturer to provide wind-rated door for 115 mph basis.
ROOM | FINISH / BASIS | CEILING
Garage/shop | sealed concrete / painted gypsum | 8 ft schematic before finishes
Mech/storage | sealed concrete / durable wall finish | 8 ft schematic before finishes
Powder/hall | tile or resilient / moisture-resistant finish | 8'-0" min
Owner flex | resilient / gypsum; classification pending | 8'-0" min

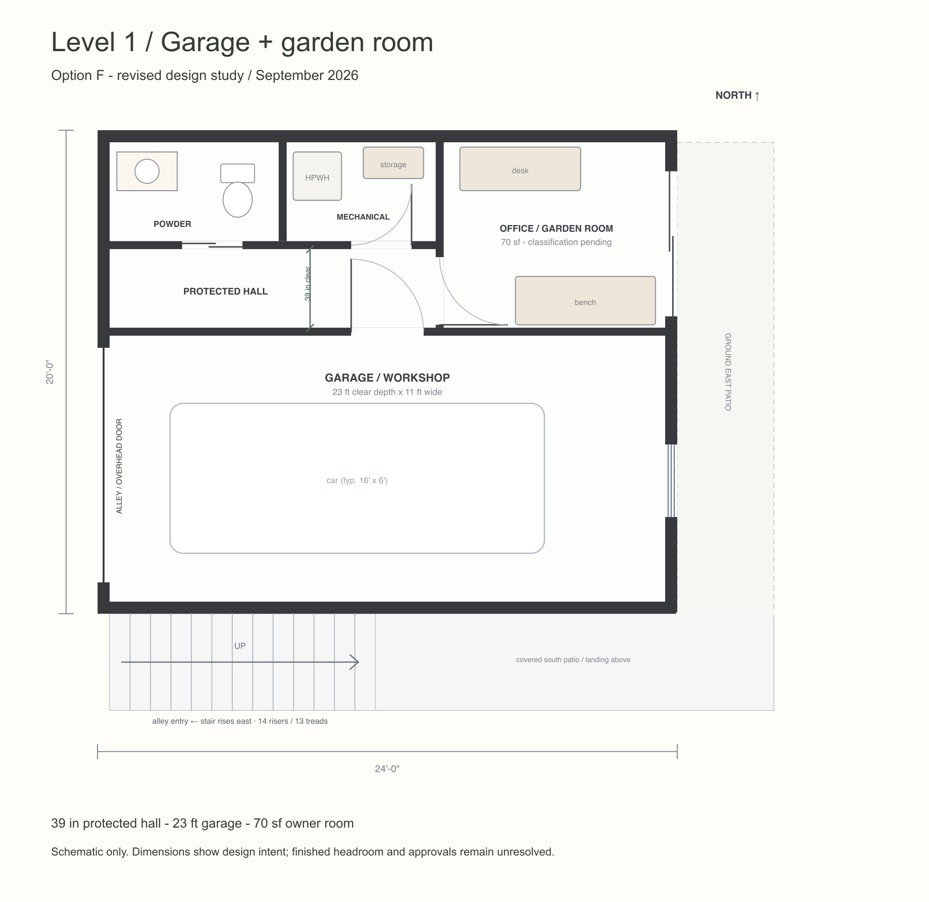
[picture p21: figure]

DIMENSIONED SCHEMATIC - NOT TO SCALE
DO NOT SCALE ELECTRONIC VIEW. DIMENSIONS TO FACE OF STUD UNLESS NOTED; EXTERIOR DIMENSIONS TO FACE OF SHEATHING.

LEVEL 2 DIMENSIONED PLAN

A102 LEVEL 2 DIMENSIONED PLAN | OPTION F / 20 FT x 24 FT / 480 SF UPPER ADU

PLAN NOTES

1. Upper gross floor area: 480 sf. Net interior basis: approximately 437 sf. Final zoning area calculation uses exterior-face definition and approved exclusions.
2. Sloped ceiling follows roof. Maintain not less than 7 ft over required area and not less than 5 ft at any included floor area; final truss/rafter geometry controls.
3. Bedroom EERO W02: select casement with at least 5.7 sf net clear, 20 in clear width, 24 in clear height, and sill not over 44 in above floor.
4. Safety glazing at doors, adjacent glazing, bath/shower, and hazardous locations per VRC R308. Confirm each product and permanently label.
5. L kitchen has 53.6 in main route, 39.6 in dining-chair aisle and 38.4 in living-slider route. Check appliance door envelopes and selected equipment before approval.
6. Apartment entry is side-hinged D05 from connected south landing; large east slider D04 is secondary patio access, not sole conventional entry.
ROOM | AREA / BASIS | CEILING
Bedroom | 92 sf clear; queen + storage | sloped; finished headroom pending
Bath | stacked wet core | sloped; fixture clearances pending
Kitchen/living/dining | open plan | project ridge +19.833 ft
Laundry/storage | low-eave service zone | sloped; verify equipment clearance

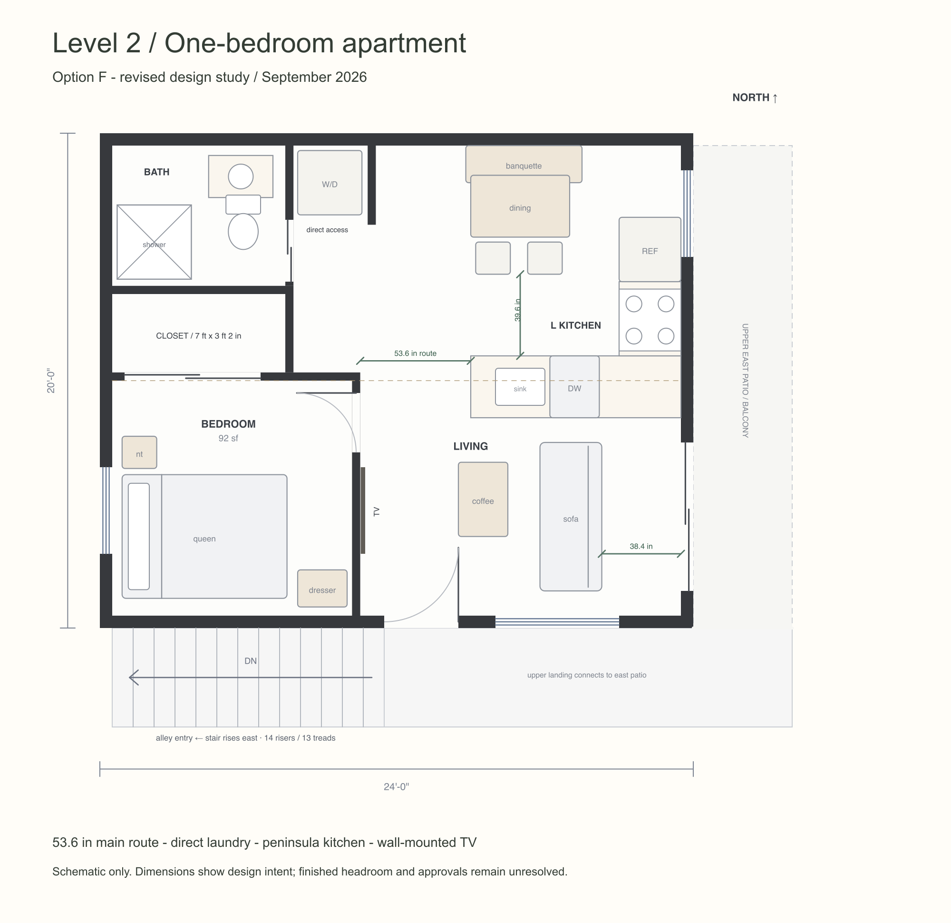
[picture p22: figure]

DIMENSIONED SCHEMATIC - NOT TO SCALE
DO NOT SCALE ELECTRONIC VIEW. DIMENSIONS TO FACE OF STUD UNLESS NOTED; EXTERIOR DIMENSIONS TO FACE OF SHEATHING.

ROOF PLAN / OPENING SCHEDULES

A201 ROOF PLAN / OPENING SCHEDULES | OPTION F / 20 FT x 24 FT / 480 SF UPPER ADU

4.6:12 NORTH ROOF PLANE RIDGE - E/W - 19'-10" MAX BASIS

4.6:12 SOUTH ROOF PLANE

NORTH/WEST EDGES FLUSH AT SETBACK BASIS; SOUTH/EAST 12 IN OVERHANG SUBJECT TO ZONING

N

ROOF / ATTIC NOTES

1. Final system: engineered raised-heel roof trusses or engineer-designed rafters at 24 in o.c. maximum; 20 psf ground snow and 115 mph wind basis.
2. Supplier to coordinate sloped interior ceiling, room partitions, gable-end openings, mechanical penetrations, energy R-value, and maximum 19 ft 10 in ridge.
3. Provide continuous load path, uplift connectors at every truss/rafter, gable bracing, blocking, and sheathing nailing per sealed truss/structural package.
4. Asphalt shingles over code-compliant underlayment and 1/2 in minimum roof sheathing basis; final thickness/fastening by span and wind design.
5. Ventilation strategy by final energy/envelope designer. Do not combine vented and unvented assemblies; avoid soffit vents at setback edges if fire-separation rules prohibit them.
6. Gutters and downspouts coordinated with site drainage. Ice barrier, drip edge, flashing, crickets, and penetration boots per adopted code and manufacturer.
MARK | SIZE BASIS | TYPE / NOTES
D01 | 9.7 ft x 7.5 ft | wind-rated sectional overhead; engineered portal/header
D02 | 3'-0" x 6'-8" | garage/hall protected, self-closing
D03 | 6 ft x 6.67 ft | level-1 east slider; safety glazing
D04 | 6 ft x 6.67 ft | level-2 east slider; safety glazing
D05 | 3 ft x 6.67 ft | upper apartment entry; outswing/inswing verify
MARK | SIZE BASIS | TYPE / PERFORMANCE
W01 | 3 ft x 3.5 ft | garage awning/fixed; tempered if hazardous
W02 | 3.5 ft x 3.5 ft | bedroom casement; EERO product data required
W03 | 5 ft x 3.5 ft | south living; safety glazing check
W04 | 3.5 ft x 3.5 ft | east dining; operable/fixed per ventilation
ALL | manufacturer RO | U <= 0.30 working basis; SHGC <= 0.40

EXTERIOR ELEVATIONS

A301 EXTERIOR ELEVATIONS | OPTION F / 20 FT x 24 FT / 480 SF UPPER ADU

WEST / ALLEY ELEVATION

SCHEMATIC - OPENINGS FROM SHARED GEOMETRY

EAST / YARD ELEVATION

SCHEMATIC - OPENINGS FROM SHARED GEOMETRY

SOUTH ELEVATION

SCHEMATIC - OPENINGS FROM SHARED GEOMETRY

NORTH ELEVATION

SCHEMATIC - OPENINGS FROM SHARED GEOMETRY

ELEVATION / EXTERIOR NOTES

1. Project Z datum: lower slab +0.5 ft; upper subfloor +9.25 ft; eave +16 ft; ridge +19.833 ft. Upper subfloor is 8.75 ft above lower slab. Survey average adjacent grade before finalizing height.
2. Exterior wall basis: fiber-cement lap siding over drained/ventilated rainscreen, continuous water-resistive barrier, taped structural sheathing, 2x6 framing, cavity insulation, smart vapor retarder where required, and gypsum interior finish.
3. North and west walls sit at working minimum yards. Keep north wall without openings; show flush north eave and flush west rake until Zoning confirms projections or building is relocated inward.
4. Exterior wood exposed to weather shall be naturally durable or preservative treated. Provide corrosion-resistant fasteners/connectors compatible with treatment and flashing.
5. Patio/landing guards shown diagrammatically. Final design must resist prescribed guard loads, reject a 4 in sphere, and include graspable stair handrail 34-38 in above nosings.
6. Finish palette: muted green-gray lap siding, light trim/guards, dark red-brown doors/windows, dark roof. Final colors do not affect code but historic/design review may apply.

BUILDING SECTIONS / ENVELOPE

A401 BUILDING SECTIONS / ENVELOPE | OPTION F / 20 FT x 24 FT / 480 SF UPPER ADU

7 FT CONTOUR - PROVISIONAL

SOUTH | NORTH / BATH FIXTURES

GARAGE / OWNER SUPPORT

PROJECT Z +9.25 FT

Roof allowance 0.85 ft assumed; finished headroom unresolved.
Project Z: slab +0.5 / upper +9.25 / eave +16 / ridge +19.833 ft.
SECTION A - BATH FIXTURE SECTION / NOT TO SCALE

RIDGE SECTION - AT KITCHEN PENINSULA

GARAGE / OWNER SUPPORT

PROJECT Z +9.25 FT

Roof allowance 0.85 ft assumed; finished headroom unresolved. Project Z: slab +0.5 / upper +9.25 / eave +16 / ridge +19.833 ft.
SECTION B - RIDGE / NOT TO SCALE

FIBER-CEMENT SIDING + RAINSCREEN

WRB / FLASHED OPENINGS

7/16 IN STRUCTURAL SHEATHING

2x6 STUDS @ 16 IN O.C. / R-20+5ci BASIS

1/2 IN GYPSUM; AIR-SEAL CONTINUITY

RIM / FLOOR TRUSS - R-30 FLOOR BASIS

5/8 IN TYPE X GARAGE CEILING

TYPICAL WALL / FLOOR EDGE - NTS

ENVELOPE BASIS

1. Working prescriptive targets for Climate Zone 4A: U-0.30 windows, R-60 roof/ceiling, R-20+5ci wood walls, R-30 floor over unconditioned garage. Final REScheck/approved alternative governs.
2. Sloped roof without attic may use approved reduced cavity R-value only where code permits; exterior continuous insulation or raised framing likely needed to preserve headroom and condensation control.
3. Continuous air barrier around conditioned upper level. Seal rim, top plates, penetrations, bath/laundry, and transition to rated garage ceiling. Blower-door target per adopted energy code.
4. No shared garage return air. Ducts/air handlers serving dwelling remain inside conditioned envelope where practical.

FOUNDATION / FIRE SECTION BASIS

1. Continuous footing bottom at least 18 in below finished grade and on undisturbed competent soil. Preliminary footing size is not final without soil and load verification.
2. Termite treatment/protection, capillary break, sill sealer, pressure-treated sill, anchor bolts, and flashing per adopted code and site conditions.
3. Garage ceiling below dwelling: listed assembly with 5/8 in Type X minimum at garage side; protect bearing elements and penetrations. Do not install unlisted recessed fixtures in rated membrane.
4. Smoke alarms inside/outside sleeping area and on each story; CO alarms outside sleeping area and on garage-adjacent story. Interconnect with battery backup.

FOUNDATION / FRAMING BASIS
ISSUE 2026-09-30 | DRAWN FOR OWNER COORDINATION | S101
S101 FOUNDATION / FRAMING BASIS | OPTION F / 20 FT x 24 FT / 480 SF UPPER ADU

FOUNDATION PLAN - NOT TO SCALE

4 IN SLAB / PERIMETER STEM + FOOTING BASIS

STAIR / LANDING PIERS - ENGINEER SIZE / FROST DEPTH

LEVEL 2 FLOOR FRAMING - NOT TO SCALE

20 FT SPAN ENGINEERED FLOOR TRUSSES / I-JOISTS

SPAN N-S; OPEN-WEB PREFERRED FOR MEP

ROOF FRAMING - NOT TO SCALE

ENGINEERED SCISSOR / PARALLEL-CHORD TRUSS BASIS

ELEMENT | PRELIMINARY BASIS ONLY | FINAL REQUIREMENT
Exterior footing | 16 in wide x 8 in thick continuous; (2) #4 cont. | Engineer/geotech verify soil, loads, steps, reinforcement
Stem wall | 8 in concrete/CMU; #4 vertical at 48 in o.c. basis | Final height/reinforcing and drainage by site condition
Slab | 4 in, 3,500 psi; fiber or WWF basis; 10 mil vapor retarder | Jointing, thickening, garage slope, termite treatment
Floor | 9 in schematic floor zone only; member depth unresolved | Engineer depth, loads and floor datum; revise headroom to suit
Garage header | (3) 1-3/4 x 11-7/8 LVL placeholder | Sealed calculation and portal-frame/hold-down design
East sliders | (2) 1-3/4 x 9-1/2 LVL placeholder | Sealed calculation; point loads carried to foundation
Roof | engineered trusses at 24 in o.c. max; 4.6:12 exterior | Sealed truss package, bracing, reactions, uplift
Stair/patio | 6x6 posts; built-up beams; 2x8 joists placeholder | Engineer/member tables, lateral, guards, footing sizes
Wall bracing | 7/16 structural sheathing continuous; portal at garage | Braced-wall calculation, nailing, hold-down schedule

STRUCTURAL HOLD POINTS

1. No structural size on this sheet is approved for procurement or construction.
2. Engineer to establish dead loads including finishes, counters, tile, deck, and MEP.
3. Carry concentrated header/truss loads to footing with posts and squash blocks.
4. Coordinate all penetrations before fabrication. No field cuts in engineered members without written approval.
5. Provide continuous load path roof-to-foundation for 115 mph wind.

MEP / ELECTRICAL / LIFE SAFETY BASIS
ISSUE 2026-09-30 | DRAWN FOR OWNER COORDINATION | M101
M101 MEP / ELECTRICAL / LIFE SAFETY BASIS | OPTION F / 20 FT x 24 FT / 480 SF UPPER ADU

LEVEL 2 - BATH / LAUNDRY / KITCHEN

LEVEL 1 - POWDER / MECH / GARAGE

BATH GROUP | W/D | KITCHEN PENINSULA

4 IN BUILDING DRAIN -> VERIFY GRAVITY INVERT

LOWER POWDER | HPWH / MANIFOLD

PLUMBING / DWV RISER - DIAGRAMMATIC

ELECTRICAL SINGLE-LINE BASIS

EXISTING SERVICE | FEEDER / DISC | ADU PANEL

125 A PANEL WORKING BASIS - FINAL LOAD CALC CONTROLS

4-WIRE FEEDER; DETACHED-BUILDING DISCONNECT

GROUNDING ELECTRODE SYSTEM + ISOLATED NEUTRAL

AFCI/GFCI, SURGE, EV/PV READY CONDUIT AS SELECTED

NO PROCUREMENT UNTIL SERVICE CAPACITY / FAULT CURRENT VERIFIED

ELECTRICAL BASIS - 2020 NEC / VIRGINIA ADOPTION

MECHANICAL / VENTILATION BASIS

1. All-electric, cold-climate variable-speed heat pump; 1.0-1.5 ton placeholder only.
2. Manual J load, Manual S equipment selection, and distribution design required.
3. Preferred: compact ducted air handler inside conditioned upper core; no garage return air.
4. Whole-dwelling ventilation sized to adopted code; balanced ERV basis if feasible.
5. Bath exhaust direct outdoors; range hood direct outdoors and sized/makeup-air coordinated.
6. Dryer vent shortest route outdoors; listed duct, cleanout access, no concealed screws.
7. HPWH in sealed/insulated level-1 mechanical closet or ducted per manufacturer; manage noise/condensate.
SYSTEM | LOCATIONS / BASIS | FINAL ACTION
Smoke alarms | inside bedroom, outside bedroom, each story; interconnected | Electrical plan and adopted R314
CO alarms | outside bedroom and garage-adjacent story | Adopted R315 / product listing
Receptacles | dwelling wall spacing; kitchen, bath, laundry, exterior, garage | NEC layout / AFCI-GFCI
Lighting | stairs/landings, exterior doors, garage, rooms; high efficacy | 3-way stair controls / energy code
Fire separation | garage ceiling/supports, protected door, sealed penetrations | Listed assemblies and inspection
Water protection | pans/leak sensors at HPWH and washer | Approved drains/shutoffs

MEP COORDINATION HOLDS

1. Trade designers own final sizing, permits, and installation documents.
2. Verify existing service, water pressure, sewer route/invert, and utility provider rules before foundation.
3. Keep plumbing in stacked wet core and route floor penetrations away from engineered member no-cut zones.
4. Air-seal and firestop every garage separation penetration with listed systems.
5. Coordinate exterior equipment clearances with property line, windows, stair, drainage, and noise.

SPECIFICATIONS / CLOSEOUT CHECKLIST
ISSUE 2026-09-30 | DRAWN FOR OWNER COORDINATION | G003
G003 SPECIFICATIONS / CLOSEOUT CHECKLIST | OPTION F / 20 FT x 24 FT / 480 SF UPPER ADU
DIVISION | SCHEMATIC BASIS | REQUIRED BEFORE CONSTRUCTION
01 General | Field verify; protect occupied house; maintain egress and utilities | Permit set, contractor scope, schedule, insurance, safety plan
02 Existing | Remove 12 x 18 field shed; protect trees/fence; reconcile assessor record | Demo permit/zoning, utility locate, hazardous-material review
03 Concrete | 3,500 psi basis; continuous footings/stem; 4 in slab | Geotech/soil verification, engineered foundation, mix/joint plan
06 Wood | 2x6 walls; engineered floor/roof; PT exterior framing | Sealed calculations, shop drawings, connector/fastener schedule
07 Envelope | WRB, rainscreen, fiber cement, asphalt roof, continuous air barrier | Hygrothermal/energy check, flashing details, product approvals
08 Openings | wind-rated windows/doors; EERO; safety glazing | Manufacturer data, rough openings, U/SHGC, design-pressure ratings
09 Finishes | durable garage finish; moisture-resistant wet areas | Owner selections, flame/smoke compliance, substrate coordination
21 Fire | alarms; garage separation; fireblocking | Listed assemblies, penetration systems, inspection sign-off
22 Plumbing | stacked wet core; all-electric DHW; gravity sewer basis | Trade permit, fixture-unit sizing, sewer invert, water service
23 HVAC | heat pump + balanced ventilation basis | Manual J/S/D, ventilation calculation, condensate plan
26 Electrical | 125 A panel placeholder; all-electric loads | Service/load calc, feeder, grounding, circuiting, trade permit
31 Earthwork | positive drainage; compacted subbase; erosion controls | Survey, grading/drainage plan, RESMP determination

OWNER DECISIONS

1. Confirm Option F as final layout and whether lower flex room remains owner-only/non-ADU space.
2. Choose flush setback-side roof edges or authorize survey/zoning study for inward shift and overhangs.
3. Confirm exterior stair weather protection, decking material, guard style, and maintenance access.
4. Confirm all-electric program, EV/PV readiness, induction cooking, dryer type, and HPWH location.
5. Select window operation while preserving bedroom EERO, natural ventilation, privacy, and safety glazing.
6. Choose foundation strategy after survey/soil: slab/stem basis versus crawlspace or engineered thickened edge.
7. Confirm budget and whether replacement shed is same-phase construction.

PRE-PERMIT COMPLETION CHECKLIST

1. Boundary/topographic survey with grades, easements, structures, trees, and utility evidence.
2. Written Zoning confirmation: ADU area/exclusions, lower flex/powder classification, setbacks/projections, height, lot coverage, shed, access.
3. Architectural permit drawings with fully dimensioned plans, four elevations, sections, openings, finishes, stair/guard details, and code analysis.
4. Structural package: soil basis, foundation, floor/roof layouts, headers, portal/lateral design, deck/stair, braced-wall information, calculations and seals where required.
5. Energy compliance: REScheck or prescriptive schedule; final window values, assemblies, air sealing, ventilation, and equipment efficiencies.
6. Separate trade designs/permits and utility approvals; confirm Fire/Public Works/Water Resources routing.

CONSTRUCTION / INSPECTION HOLD POINTS

1. Preconstruction: approved plans on site, survey staking, erosion controls, utility locate, tree protection.
2. Footing: bearing soil, location, depth, size, reinforcing, and step geometry before concrete.
3. Foundation/slab: forms/CMU, anchorage, underslab trades, subbase, vapor retarder, reinforcement, termite provisions.
4. Framing: approved engineered packages, member sizes, nailing, bracing, hold-downs, connectors, fireblocking, rough trades before concealment.
5. Fire separation/insulation: rated membrane and penetrations; air barrier and R-values before cover.
6. Final: stairs, guards, alarms, EERO, safety glazing, address, drainage, trade finals, zoning/land-disturbance/public-works finals, certificate of occupancy.

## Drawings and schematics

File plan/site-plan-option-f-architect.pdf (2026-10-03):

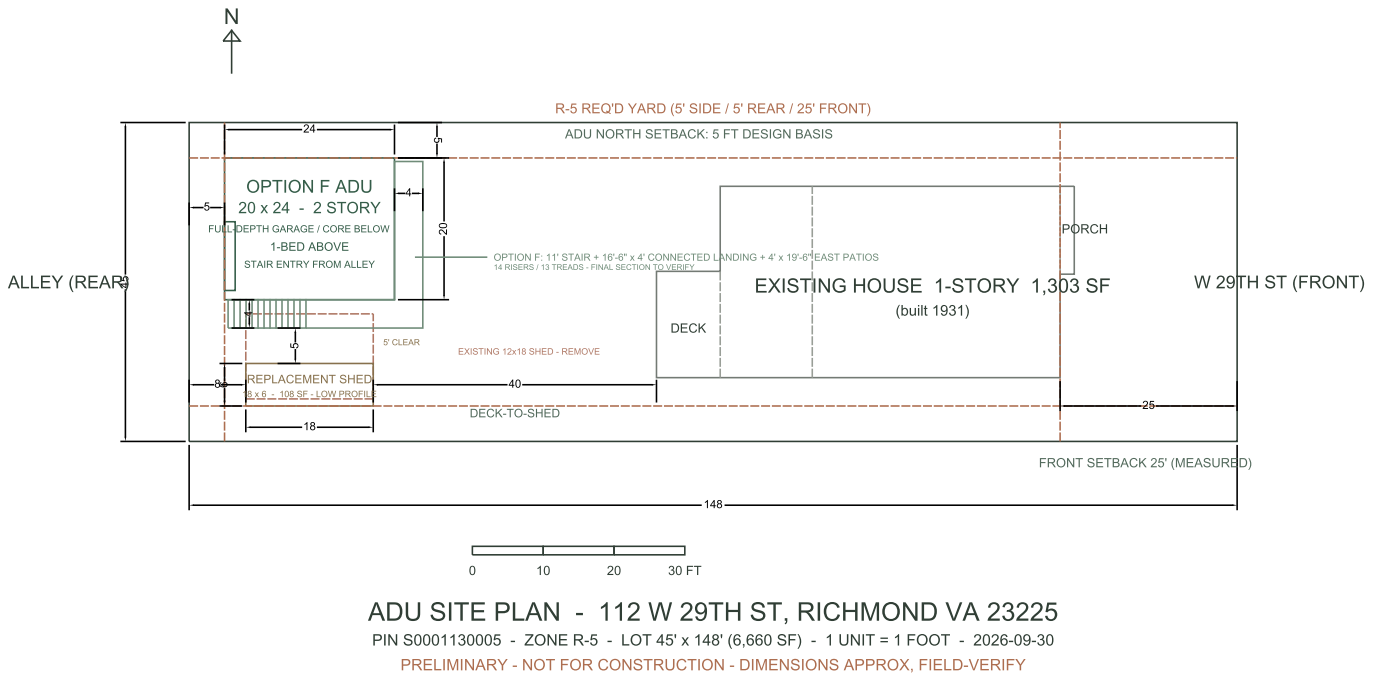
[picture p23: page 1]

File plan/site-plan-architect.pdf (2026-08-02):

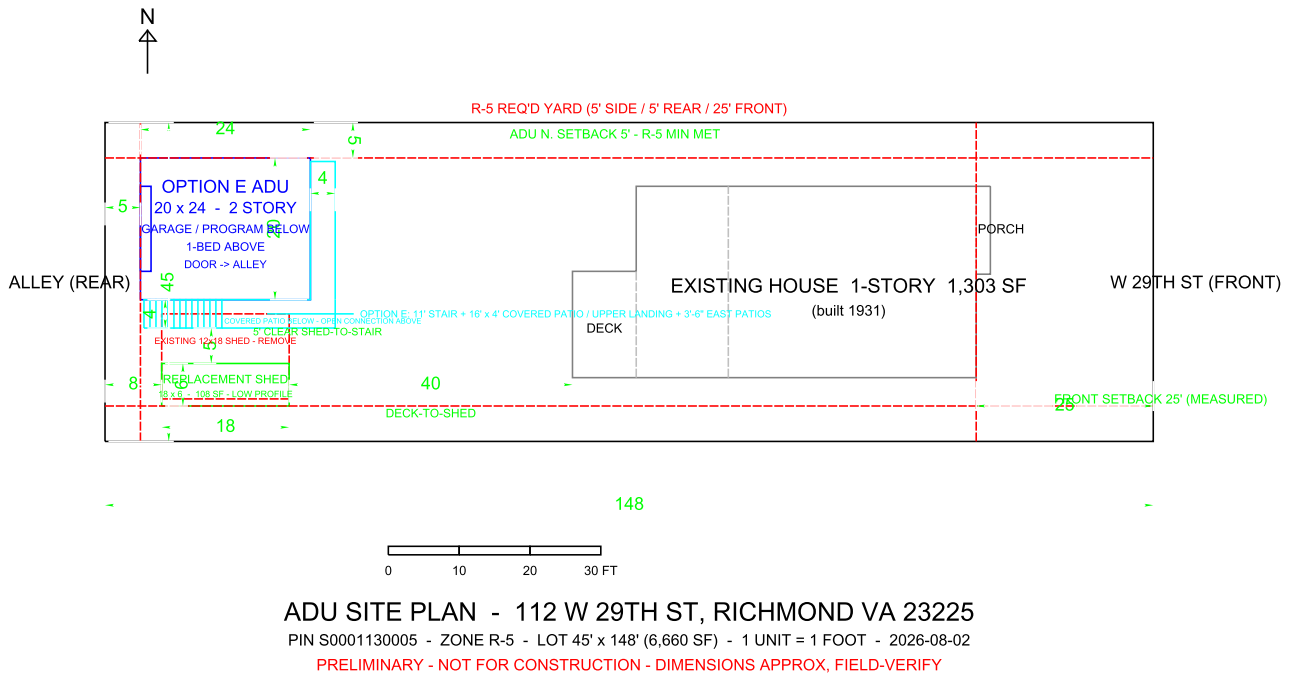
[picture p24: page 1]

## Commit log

2026-06-28 Add source documents dir and resources list
    - documents/: DataScout property report (PIN S0001130005), assessor
    building sketch, and a compressed copy of the hand-drawn site plans
    (rebuilt from 57 MB original down to ~1.2 MB)
    - README: fold in confirmed property-record facts (1,303 sf, built 1931,
    3bd/2ba, garage-vs-shed discrepancy) and add a Resources & sources
    section (Municode Ch.30 sections, rva.gov, actDataScout, contacts)
2026-06-28 Add architect-ready CAD site plan (DXF + PDF)
    - plan/site-plan.dxf: true-scale (1 unit = 1 ft) layered CAD file with
    lot boundary, existing house/shed footprints, proposed 20x24 ADU,
    R-5 required-yard setback lines, dimensions, north arrow, scale bar,
    and title block
    - plan/site-plan-architect.pdf: printable render of the DXF
    - plan/generate_site_plan.py: reproducible generator (ezdxf + matplotlib);
    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
    [site-plan.dxf]
2026-06-28 Lock house placement to measured front setback (25 ft)
    Field measurements (2026-06-28): main east wall 25 ft off the front
    property line; front porch projects ~2 ft (was drawn at 7). House
    shifts accordingly; deck-to-shed clear distance resolves to ~40 ft
    (the earlier ~17 ft was a mismeasurement, now reconciled).
    Updates DXF/PDF (via generator), the colored SVG/PNG, and the README
    (front setback + porch now confirmed; open items narrowed to the 3 ft
    north-setback variance and the shed-vs-garage footprint).
    [site-plan.dxf]
2026-06-28 Add 5 more inspiration references and index themes
    Five garage-ADU references (modern taupe shed-roof, craftsman gray
    w/ red trim + carriage door, olive cottage, brick shed-roof, modern
    olive corner-glass). README notes two emerging directions: craftsman-
    traditional vs modern shed-roof with dark windows, plus a brick option.
2026-07-03 Add 3D lot massing model: OBJ export + interactive HTML viewer
    - model/generate_3d_model.py builds house/shed/proposed-ADU massing from
    the measured site-plan geometry (1 unit = 1 ft, stdlib only)
    - site-model.obj/.mtl: true-scale Y-up OBJ for SketchUp/Blender
    - site-model-3d.html: self-contained orbit/zoom/pan viewer with layer
    toggles, preset views, R-5 setback lines, and neighbor context massing
    Claude-Session: https://claude.ai/code/session_01QqTb3FtXKZsBHVMqNdWPNr
    [site-model.obj]
2026-07-04 Add apartment floor-plan studies: 3 layout options + iteration framework
    Three furnished layout sheets (garage + apartment levels) for the 1-bed
    above the garage, generated by a parametric stdlib-Python script:
    - Option A: interior stair on the north wall, living toward the yard
    - Option B: same core, bedroom toward the yard, kitchen on the west wall
    - Option C: exterior stair on the east face, maximum interior space
    All three share one plumbing core (NW bath + stacked W/D over a garage
    mech corner). apartment/README.md documents the fixed constraints, the
    three decisions that drive the layout, code sanity numbers, and how to
    iterate by editing generate_floorplans.py.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
2026-07-04 Add Pinterest board → inspiration/ sync (RSS) with weekly cron (#3)
    One-way pull from a public Pinterest board into inspiration/ via RSS (no token). Includes 12 pins from swansonanders/adu-inspo and a weekly GitHub Actions cron to auto-pull new pins.
2026-07-04 Add ruff and ty checks as pre-commit hooks and CI (#4)
    Set the repo up as a uv/Astral-toolchain project and wire linting,
    formatting, and static type checking into both pre-commit and CI:
    - pyproject.toml: declare runtime deps (ezdxf, matplotlib) so ty can
    resolve imports, a dev group (ruff, ty), plus ruff and ty config.
    - .pre-commit-config.yaml: ruff-check (--fix), ruff-format, and a local
    uv-driven ty hook that runs in the project env.
    - .github/workflows/lint.yml: separate ruff and ty jobs on push/PR.
    - Fix existing violations so the checks pass green: drop an unused import
    and a dead variable, sort imports, apply ruff format across all
    scripts (incl. sync/pinterest_pull.py), an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
2026-07-04 Add balcony-entry scheme: two-floor plans, interactive 3D massing model
    - plan/floor-plans-balcony-scheme.{svg,png}: both floors from the owners'
    sketch — exterior S stair to a covered 6x20 E balcony (sole entry, no
    interior stair), garage/office/sunroom/bath down, 480 sf 1-bed up
    - ridge flipped E-W (front gable to alley) so the balcony gets a
    full-height gable wall; kitchen therefore moves off the N knee wall
    onto the tall TV-wall partition
    - renderings/massing-3d-interactive.html: self-contained canvas 3D
    massing model (orbit, exterior/upstairs/downstairs cutaways) + a
    captured alley view PNG
    - README: v2 design direction, area math, new open questions (500 sf
    counting of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
2026-08-02 Tighten architect handoff site
2026-08-02 Update site plan for Option E access
    [site-model.obj, site-plan.dxf]
2026-08-03 Add editable Option E CAD and floor plans
    [adu-option-e-arch.obj, adu-option-e-sweethome-simple.obj, adu-option-e-sweethome.obj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]
2026-08-03 Add Option F ADU concept package
    [site-plan-option-f.dxf]
2026-08-03 Coordinate Option F models and renderings
    [adu-option-f.obj, adu-option-f.step, site-model.obj]
2026-08-12 Add 3D model tab to ADU site
    [site-model.obj]
2026-08-12 Improve 3D model layer filters
2026-09-30 Coordinate revised ADU plans, model renderings, and website
    [adu-option-f.obj, adu-option-f.step, site-model.obj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]
